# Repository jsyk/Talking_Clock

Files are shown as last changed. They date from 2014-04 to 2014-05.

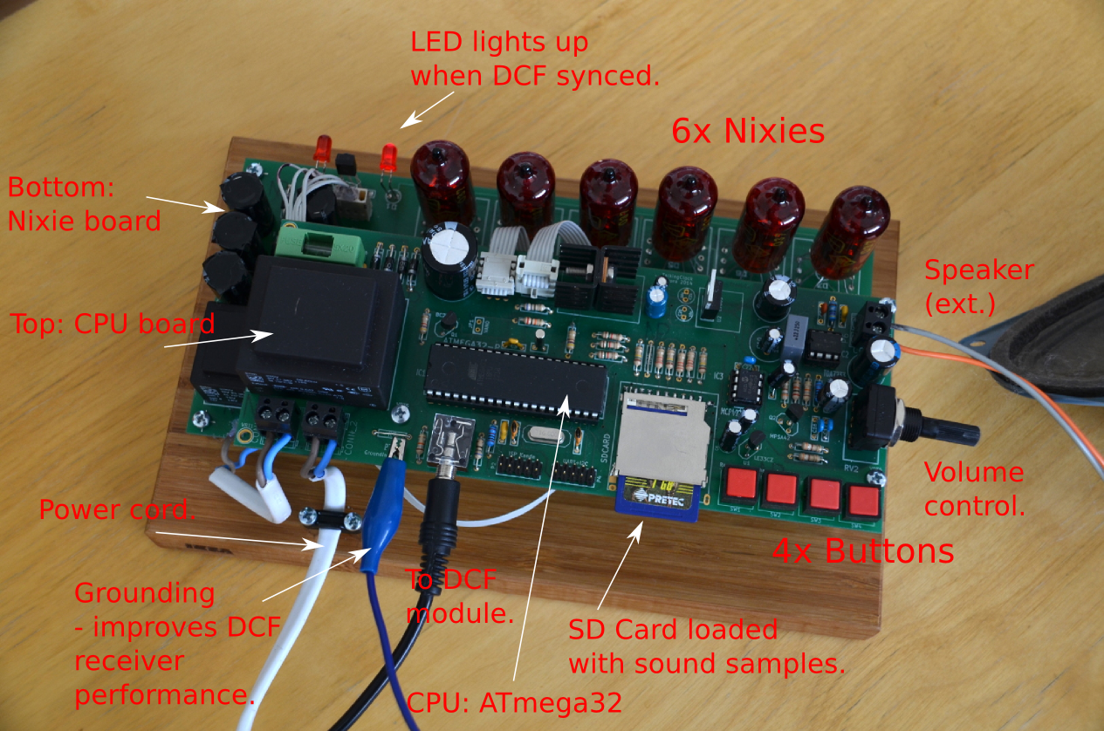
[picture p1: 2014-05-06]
doc/tc_topview_marked.png

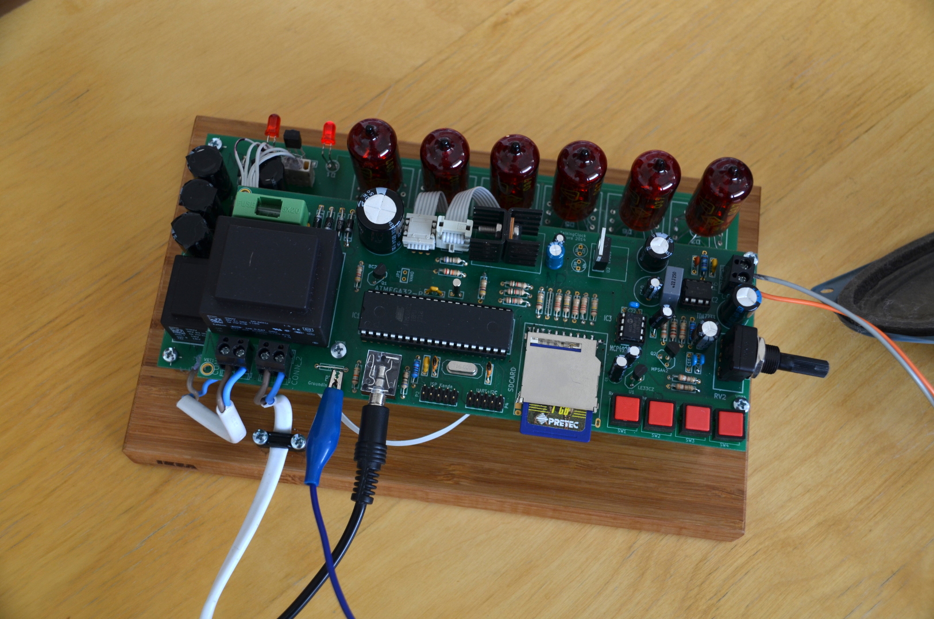
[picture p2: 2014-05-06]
doc/tc_topview.jpg

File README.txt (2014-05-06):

Talking Clock
===============

See
    http://www.jsykora.info/?page_id=240
and
    http://hackaday.io/project/1082-Talking-Nixie-Clock
for more details.

Firmware for ATMEGA32 CPU is in the sw-mega32 directory. Use AVR gcc (a package in Fedora YUM is available) to compile by Makefile, and use uisp to download compiled hex file into AVR CPU via ISP cable.
Schematic and PCB drawings in KiCAD format for the nixie board and the CPU board are in the nixieboard and rcmainboard directories, respectively.

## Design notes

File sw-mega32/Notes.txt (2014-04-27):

Use AVR gcc (a package in Fedora YUM is available) to compile via Makefile,
use uisp to download hex file into AVR CPU via ISP cable.

--------------------

uisp -dprog=stk200 --erase --upload if=dcfnix.hex --verify

uisp -dprog=stk200 --rd_fuses

picocom /dev/ttyS0 -b38400 -c

External XTAL 8MHz
    CKSEL3:1 = 111
    CKSEL0 = 1
=>
    Fuse low byte = 0xEF
uisp -dprog=stk200 --wr_fuse_l=0xef

External XTAL 16MHz
    CKSEL3:1 = 111
    CKSEL0 = 1
    CKOPT = 0
=>
    Fuse low byte = 0xEF
    Fuse high byte = 0x89
uisp -dprog=stk200 --wr_fuse_l=0xef --wr_fuse_h=0x89

Calibrated internal 8MHz RC:
    CKSEL = 0100
=>
    Fuse low byte = 0xE4
uisp -dprog=stk200 --wr_fuse_l=0xe4

Calibrated internal 1MHz RC:
    CKSEL = 0001
=>
    Fuse low byte = 0xE1
uisp -dprog=stk200 --wr_fuse_l=0xe1

mpg321 "Lordi - Dynamite Toonite.mp3" -w ~/zvuk/dynamite.wav

#sox dynamite.wav -b 8 -c 1 -r 22000 -e signed-integer dynamite.raw
sox dynamite.wav -b 8 -c 1 -r 22000 -e unsigned-integer dynamite.raw

play -r 8000 -c 1 -b 16 -L -e unsigned  dyna-u16.raw
play -r 22000 -c 1 -b 8 -L -e unsigned  dynamite.raw

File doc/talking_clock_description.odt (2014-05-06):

Talking clock can tell the current time aloud in English. The time announcement is triggered by pressing a button on a remote controller. When I awake at night I cannot recognize digits on any wall clock because I don't have my dioptrical glasses on. But I can easily find remote controller and press the trigger button just by touch, and thus learn that I don't have to get up just yet (ideally).

Besides speaking, the clock has also some other notable features. Foremost, the display is realized using six nixie tubes, which give a nice orange friendly glow. Secondly, the time is continuously kept up-to-date by receiving the German public time signal DCF77 transmitted from Frankfurt at the frequency 77.5kHz and 50kW power. The transmission covers most of the Europe up to approximately 1500km from Frankfurt. Similar transmitters exist in the UK (60kHz/50kW in Teddington, Middlesex), and in the USA (60kHz/10kW in Fort Collins).

Specification:

- Display: Six cold cathode neon readout (nixie) tubes Z573M, (or 'digitrons', as we call them here)
- Time: Radio DCF77 module receives precise German time, backed up by a 32.768kHz watch crystal.
- Remote control: infra-red (IR) sensor, software decoder for Sony remote controller I’ve got
- Processor: AVR ATmega32 (8-bit, 32kB FLASH, 2kB RAM)
- Storage of voice samples on SD card (e.g. 1GB) with FAT16/32 filesystem
- Sound converter: 12-bit DAC with SPI interface (MCP4921)
- Amplifier: 1.5W (TDA7233)
- Debug: UART/RS232, AVR ISP interface

Block Scheme

Figure 1 below shows the functional block scheme of the Talking Clock. Software components are depicted by yellow boxes and hardware parts by green boxes. The software runs on ATMEGA32 controller CPU. The IR remote controller is coloured red, because it is not a part of the design: an off-the-shelf product is used.

The lower part of the scheme in Figure 1 shows blocks dedicated to time keeping functions. There are two independent sources of the time information: a DCF radio receiver, providing a precise German date and time signal, and a local “watch” crystal oscillator. The DCF radio signal is a serial stream of bits. The bit-stream is decoded in software; more information about the decoding process is given below. The current time is updated according to the local crystal oscillator, and continuously corrected by DCF information as it is decoded. The current time expressed in hours, minutes and seconds is displayed on six nixie tubes (digitrons). Each nixie tube is capable of showing digits 0-9 and a dot.

The upper part of the functional block scheme in Figure 1 shows blocks that realize time announcements using voice. An announcement is triggered at any time by pressing a dedicated button on an infra-red (IR) remote controller. An IR signal is received by the IR sensor and output as a serial stream of bits to the CPU. If the correct button has been pressed the IR decoder triggers voice announcement. Voice messages are created by sequencing independent voice samples corresponding to individual words together. For instance, suppose the current time is 11:37. The speech sequencer first plays a voice sample that says 'it is'. Then it plays samples that say 'eleven', 'hours', 'thirty-seven', and 'minutes'. Voice samples are stored in files on SD-card (using the FAT16/32 filesystem). Analogue voice signal is synthesized using 12-bit digital-to-analogue converter (DAC), amplified, and made audible by a loudspeaker.

Nixie Display

Visual display of the clock is realized by six nixie tubes. Each Z573M tube can display digits 0-9 and a dot. Nixies produce light the same way as neon bulbs. There is a single anode at the front of the tube, made from a grid of thin wires so that you can see through it. Behind the anode there are 10 cathodes physically made of thin wires and shaped as letters '0' to '9', stacked one over another. The tube lights up when a high DC voltage (around 200V) is applied between anode and one of the ten cathodes (the dot is the eleventh cathode). A nice and friendly nuclear-age orange glow will appear around the cathode that is grounded, thus illuminating a digit.

The figure below shows the block scheme of display driver circuit. Nixies are driven in a multiplex. Cathodes of identical digits of all six nixies are connected together. Each cathode set can be switched to ground by an NPN transistor. Anodes are switched by PNP transistors. The transistors are driven from a serial shift register buffer implemented by three 74HC595's. The CPU sends a 24-bit serial stream which is shifted in the register.

Nixies require high voltage around 200V DC to light up. This power is produced in a voltage quadrupler from 36V AC.

Radio Receiver

DCF77 is a German long-wave time signal and a standard-frequency radio station located in Mainflingen near Frankfurt. The transmitter frequency is 77.5kHz, the power is 50kW.

DCF77 uses amplitude shift keying to transmit digitally coded time information. The carrier signal is 77500Hz. At the beginning of each second the amplitude of the carrier is reduced to 15% of the normal for 100ms or 200ms. A 100ms reduction denotes a binary 0; a 200ms reduction is binary 1. As a special case, the last second of every minute is marked with no carrier power reduction.

The time interval for the transfer of one bit of information is 1 second, the whole frame that encodes the current date and time takes exactly 1 minute. The figure below shows mapping of the 59-bits of a one-minute frame (the 60th second is a marker that is not modulated) to minutes, hours, and date. Numbers are encoded using BCD.

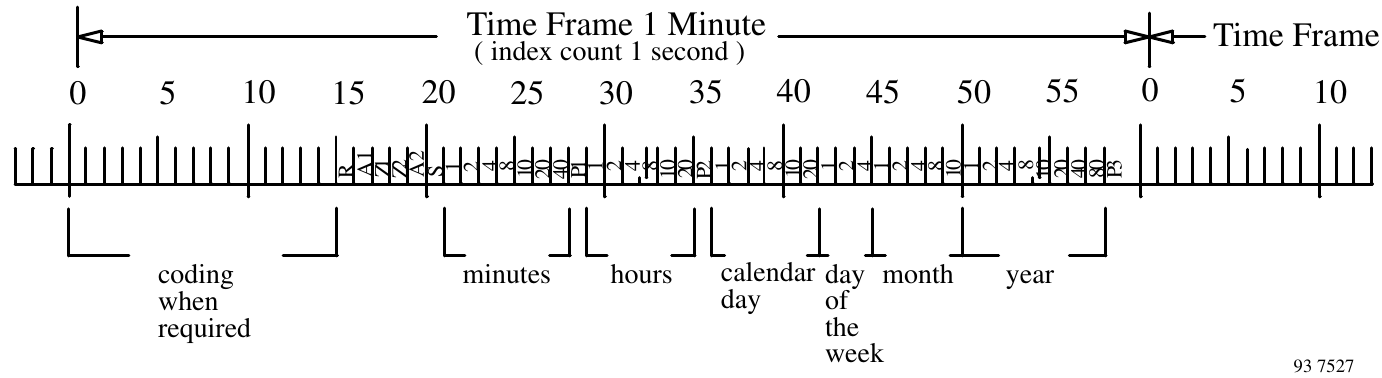
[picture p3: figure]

The talking clock uses a kit module from Flajzar that requires just power (5V), and has a single digital output corresponding to a demodulated AM signal. The module is internally realized by a ferrite antenna and U4221B integrated circuit. The output of the kit module is connected to INT1 pin at the CPU in the clock and triggers an interrupt whenever it changes level (edge detection). The interrupt routine in the CPU measures the duration of the logic levels: the duration 100ms means bit-0, and 200ms is bit-1 in the DCF bitstream. Once the whole 1-minute frame is received, it is checked for parity errors and if correct, the current time is updated to the received information.

IR Control

The clock can be controlled using an IR remote controller. The receiver module in TO92 package is mounted on the display board and connected using three wires (power and signal) the CPU board. The signal is connected to INT0 input on the CPU. Any edge triggers an interrupt. TODO Which part???

IR data is encoded by pulse width. The Sony remote that I use has three symbols that it sends: a start-bit, a zero-bit, and a one-bit. By experiment I determined that the start bit has pulse width 2.1ms to 2.75ms, one-bit is between 0.92ms and 2.1ms, zero-bit are pulses less than 0.92ms.

Each symbol (start, zero, one) is sent as a burst of on-off light pulses at the frequency roughly 38kHz. The IR module drives its output high when it detects light pulses.

http://dmohankumar.wordpress.com/2012/05/15/design-your-circuit-part-iv-ir-transmitter/

Speech

Speech synthesis is realized by playing out digital samples of individual words from SD card to DAC (digital-audio converter), and through an analogue amplifier to a loudspeaker.

Voice samples are stored in files on SD card. The SD card is formatted using standard FAT16 or FAT32 filesystem, hence the files can be normally written on any PC. The SD card hardware is connected to the ATMEGA32 CPU via SPI interface (MOSI, MISO, SCK). One minor issue is that the SD card operates on 3.3V while the rest of the design is 5V. Thankfully, all that is needed are a couple of resistors on links from CPU to the card.

The firmware has two layers of software to operate the SD-Card: SPI block-driver layer, and FAT filesystem layer. I used “Tiny FAT filesystem module” by ChaN. The SPI driver communicates with card. The card is organized into 512B-sectors. The block-layer driver can read any sector from the card and place it into internal RAM of the CPU. The FAT filesystem driver understands the FAT16/32 filesystems. It reads FAT allocation tables and directory structures. To an application it presents a simple API that allows to open a directory, list files, open a file by name, and read sequentially or randomly from the file.

Suppose the current time is 11:37. The speech sequencer first plays a voice sample that says 'it is'. Then it plays samples that say 'eleven', 'hours', 'thirty-seven', and 'minutes'. These samples are stored in files it-is.raw, n11.raw, hours.raw, n37.raw, and minutes.raw.

Sampling rate of the sound is 8kHz. Each sample is stored as 16-bit unsigned number. Samples are read from file into a working buffer (256B) and then played out at the fixed rate 8kHz through a digital-to-analog converter (DAC). The bit rate is 128kbit/s, or 16kB/s.

The DAC is connected using a separate SPI interface, which is emulated by software because ATMEGA32 has only one hardware SPI (it is used for SD-Card). The DAC is only 12-bit, hence 4 sample bits are lost. The analogue output of the DAC is filtered by a low-pass RC filter, and amplified by a single-chip 1-watt amplifier. The amplifier is powered from 12V supply.

Software

Firmware is stored in internal flash memory in the CPU. As the software must cater for several asynchronous functions concurrently, it is split in independent tasks that cooperate through shared-time multiplexing and communicate by sending messages.

Interrupt routines run in background. There are four interrupt sources: 1) precise watch-clock oscillator 32768Hz that generates periodic interrupts 128-times per second; 2) 8kHz periodic interrupt generated by CPU timer to recreate the audio sample rate; 3) burst detector in the infra-red receiver; and 4) demodulated DCF77 signal.

Low-frequency 128Hz periodic interrupt (1) is driven by external 32768Hz clock oscillator. The interrupt routine increments the current time by 1/128s.

High-frequency 8kHz periodic interrupt (2) is driven by an internal timer and the clock is derived from a CPU crystal oscillator, which is typically rather imprecise. It is used to drive the Nixie tube display multiplex (at roughly 1kHz frequency) and to output audio samples to DAC if sound is playing.

The IR burst detector (3) and DCF77 demodulator (4) each drive a separate interrupt pin at the CPU. Interrupts are generated at both the rising and falling edges of signals. The interrupt routines measure time intervals between edges, and decode signals accordingly.

Interrupt routines run in background. In foreground there are 7 `processes' which are executed in a loop. Technically, the system implements shared-time multiprocessing with message passing. Each `process' is a function with a single argument `const message_t *msg' – a pointer to the current message. The function can react to the message, it can create and send (enqueue) new messages, or it can do any other processing.

Processes:

voice_process() - Sequences current time into file names of samples that shall be played.

recv: Cmd_SayTime, Cmd_FinishedPlay; send: Cmd_PlayFileName

vfs_process()- Opens file by name and passes the handle to sound player.

recv: Cmd_PlayFileName; send: Cmd_PlayFileHandle

sound_process()- Receives file handle from VFS process, reads samples from the file and sends them at fixed rate to DAC.

recv: Cmd_PlayFileHandle; send: Cmd_FinishedPlay

ir_process()- Retrieves decoded word from IR receiver, compares to known codewords, sends Cmd_SayTime if the correct button has been pressed.

send: Cmd_SayTime

debug_process()- Communicates over UART for debug.

send: Cmd_SayTime, Cmd_PlayFileName

btn_process()- Checks hardware buttons on the CPU board.

recv: Cmd_ClockTick

clock_process()- Sends periodic clock event messages.

send: Cmd_ClockTick

Mechanical Construction

The system has two PCB boards: display board with nixies and high-voltage electronics, and CPU board with ATMEGA32, SD-Card, and sound subsystem. The CPU board is mounted over the display board and a little bit behind, so the two boards form a cascade. The board assembly is mounted on a wooden baseplate--I used a small chopping desk from Ikea. No other cover is used because I like having electronics exposed.

Errata

The PCB board has a couple of bugs, and they should be fixed by anyone wishing to replicate the design.

- Connector P1 on CPU board is package DIP-6__300ELL, but the corresponding connector P1 on nixie board is package 6DIP-CONN. While the physical footprints on PCB are the same, the logical assignment of signals to pins is different! Hence a straight flat cable between the connectors will connect incorrect signals. Suggested correction: change package and reroute a part of one of the boards.
- Drill holes for potentiometer RV2 on CPU board are small.
- Drill holes for buttons on CPU board are small.

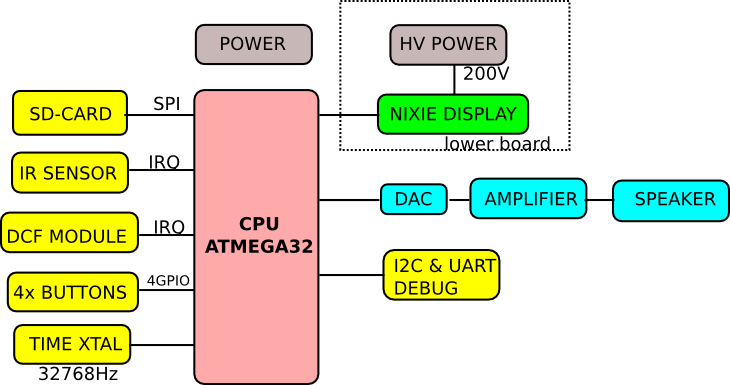
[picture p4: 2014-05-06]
doc/talkingclock_block_scheme.png

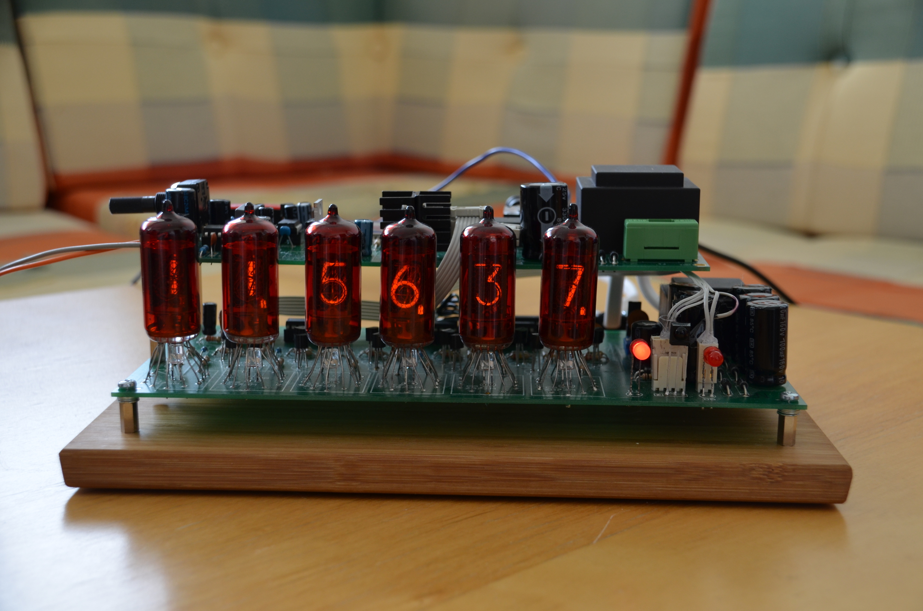
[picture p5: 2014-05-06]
doc/tc_front.JPG

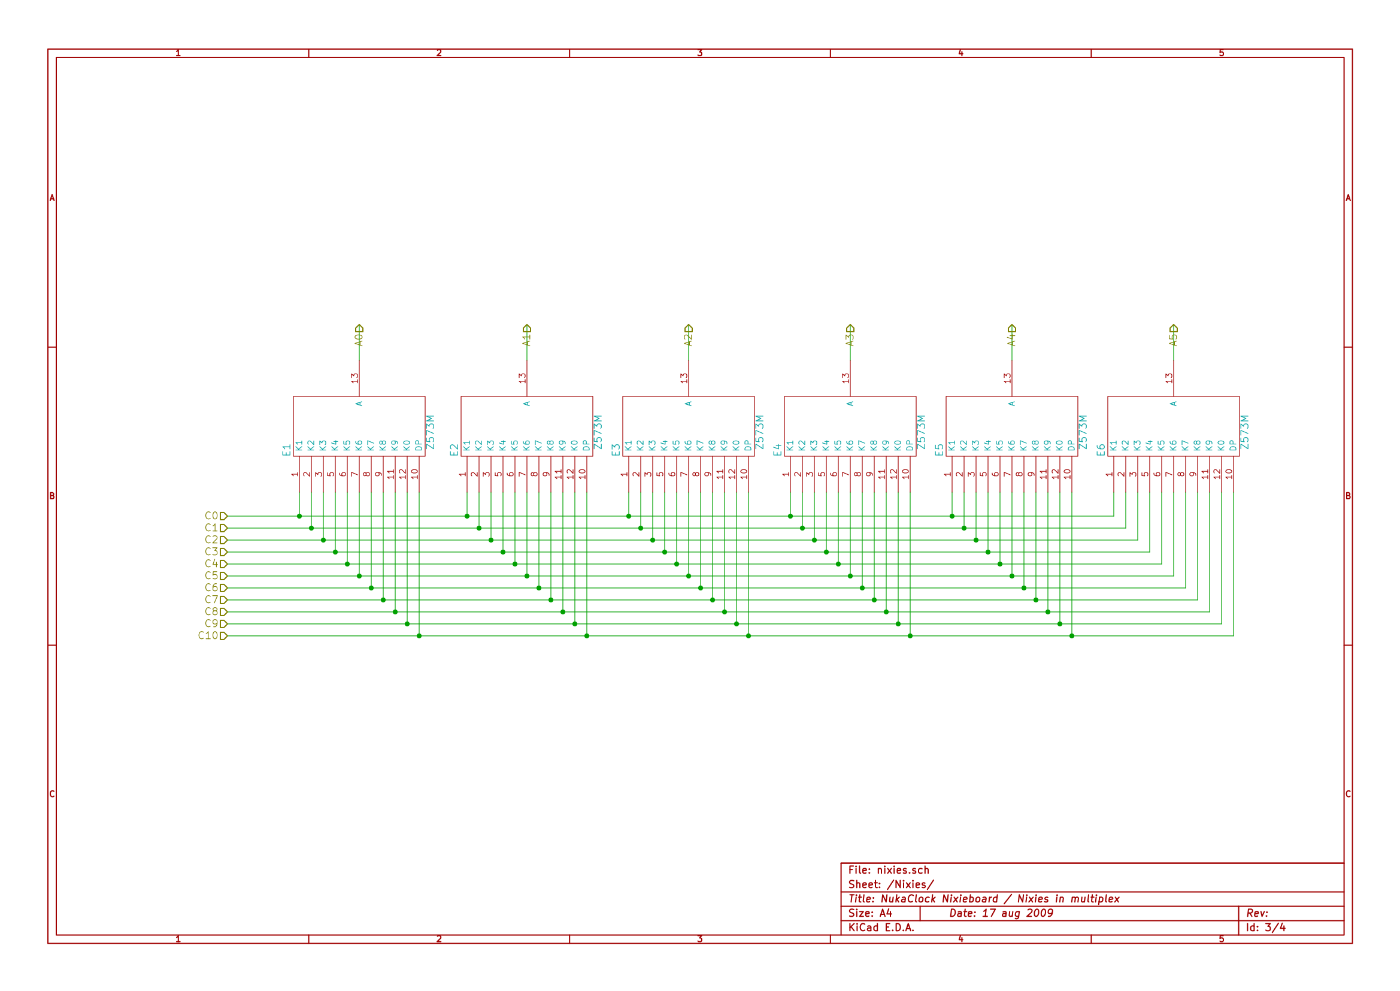
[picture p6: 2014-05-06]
doc/nixieboard_sch_nixies.png

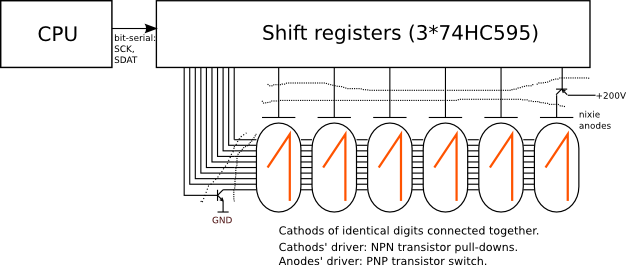
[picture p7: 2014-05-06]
doc/tc_nixie_display.png

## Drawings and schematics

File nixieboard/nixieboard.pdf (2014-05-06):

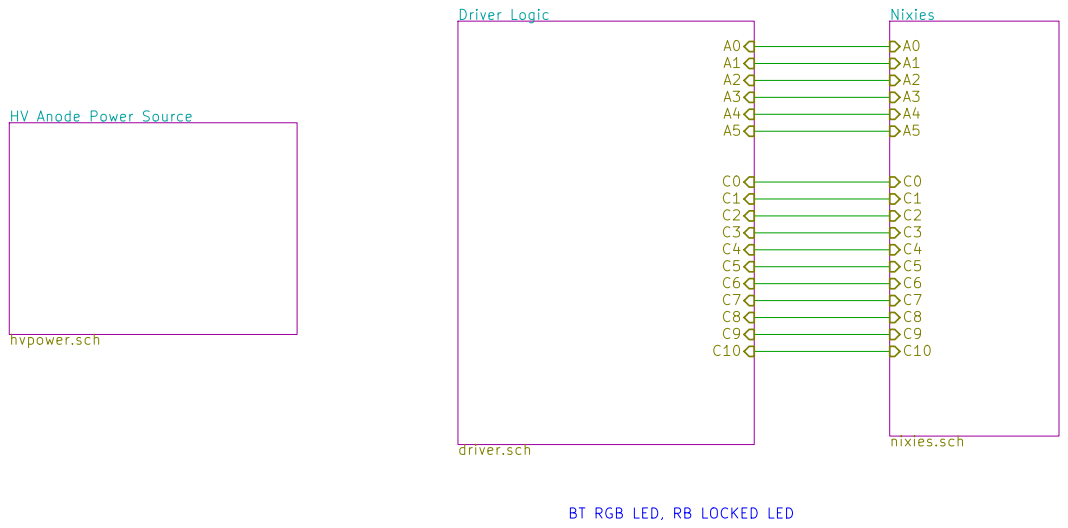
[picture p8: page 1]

HV Anode Power Source

BT RGB LED, RB LOCKED LED

Title: NukaClock Nixieboard File: nixieboard.sch Sheet: /

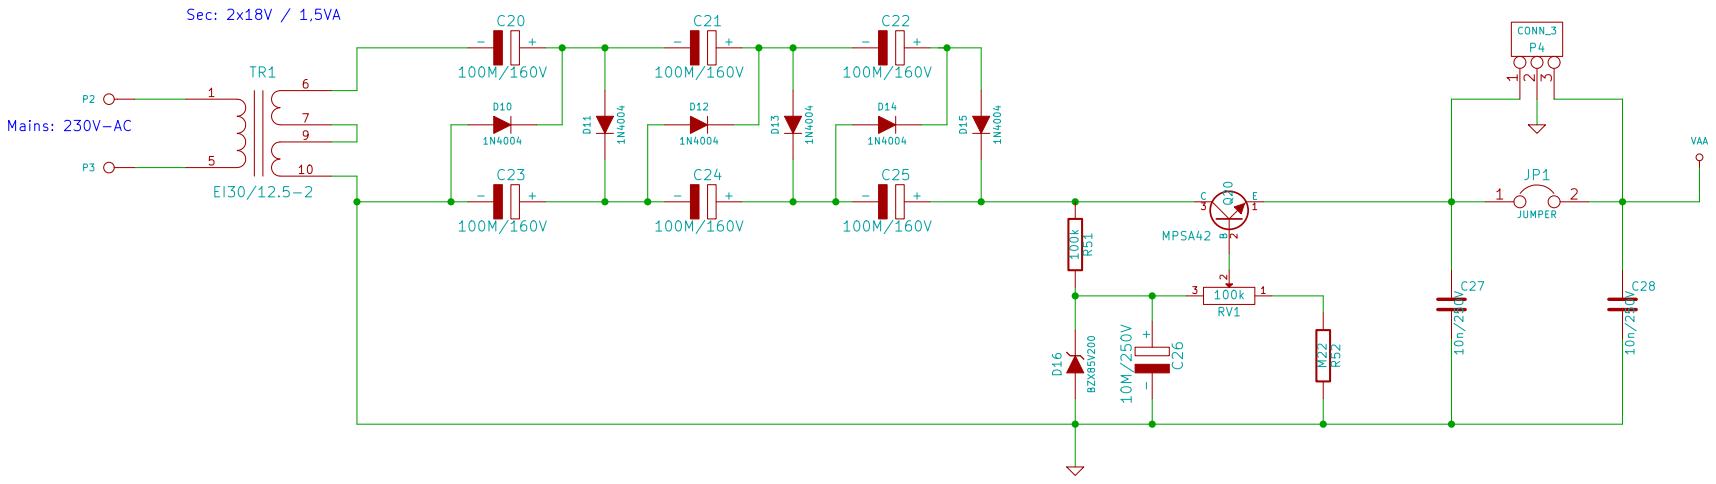
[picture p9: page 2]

File: hvpower.sch
Sheet: /HV Anode Power Source/
Title: NukaClock Nixieboard / High voltage anode power supply

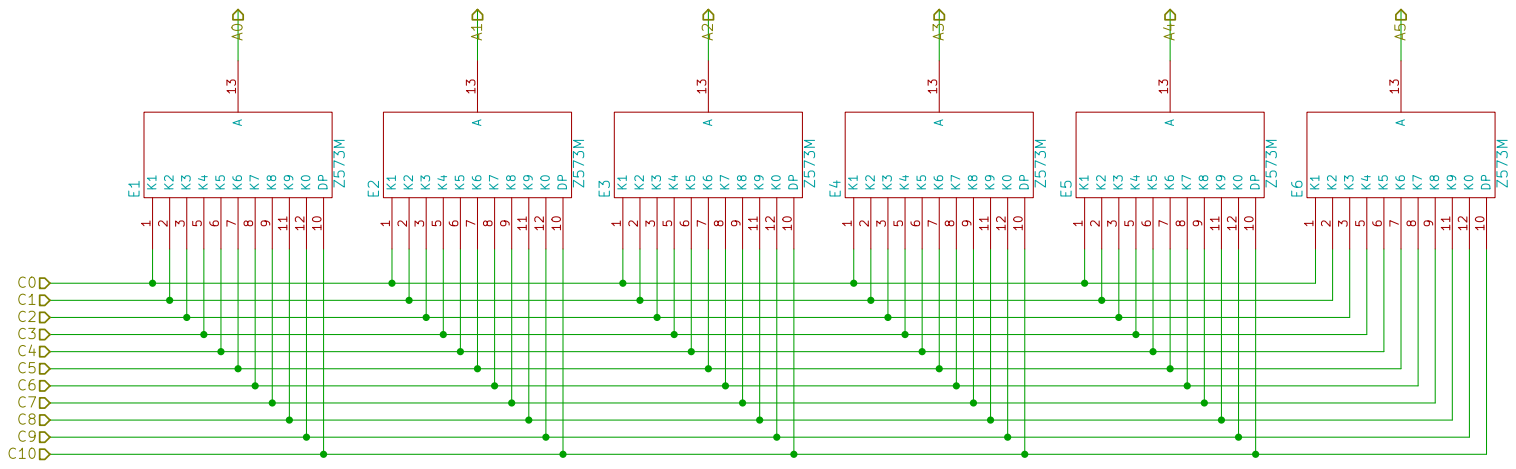
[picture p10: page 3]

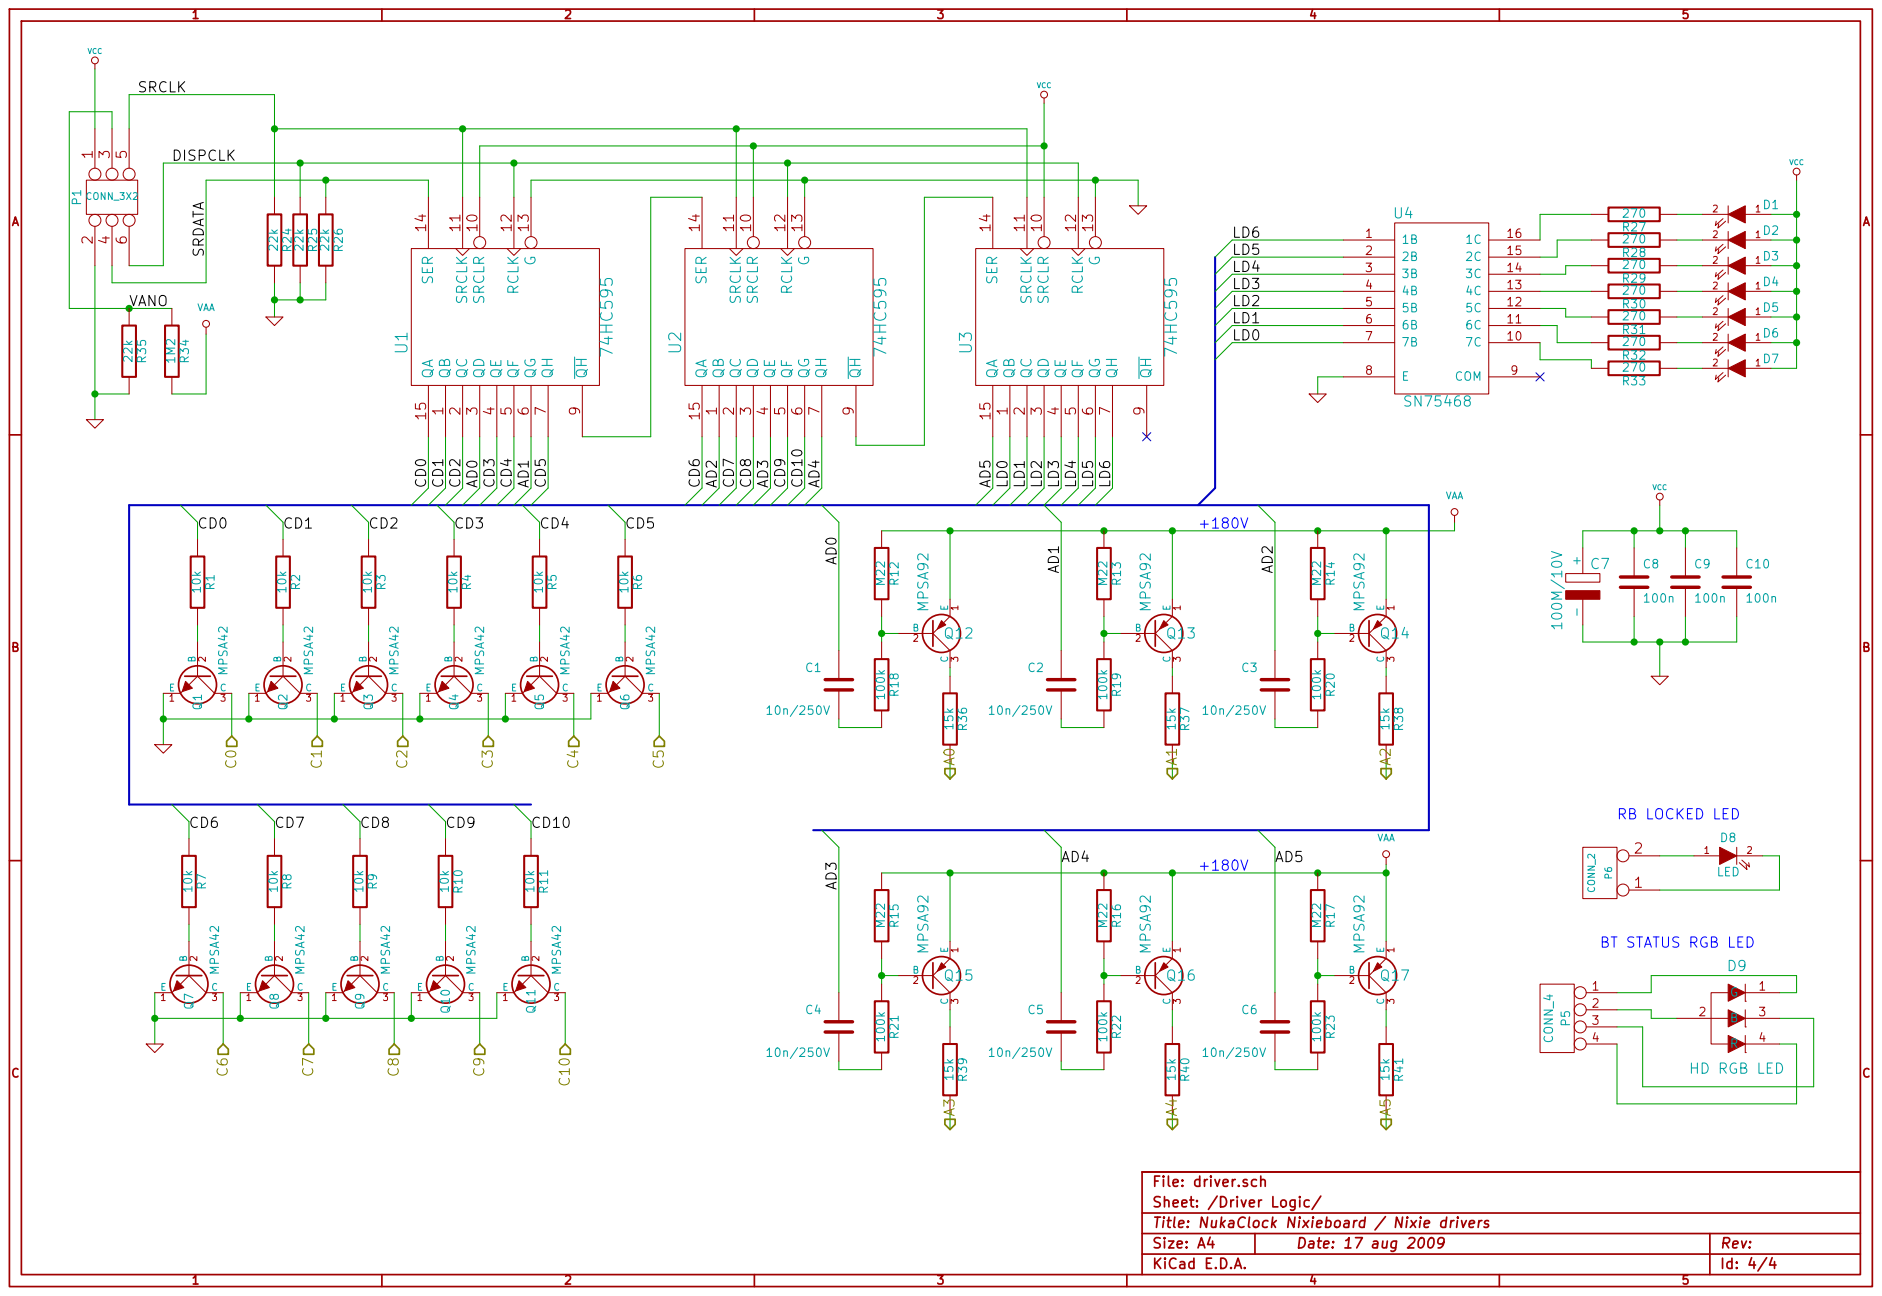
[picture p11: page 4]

VCC BT STATUS RGB LED

9 SRCLR 10 SRCLK 11 RCLK 12 G 13 SER 14 QA 15 U174HC595

9 SRCLR 10 SRCLK 11 RCLK 12 G 13 SER 14 QA 15 U274HC595 QB

9 SRCLR 10 SRCLK 11 RCLK 12 G 13 SER 14 QA 15 U374HC595 QB

Title: NukaClock Nixieboard / Nixie drivers File: driver.sch Sheet: /Driver Logic/

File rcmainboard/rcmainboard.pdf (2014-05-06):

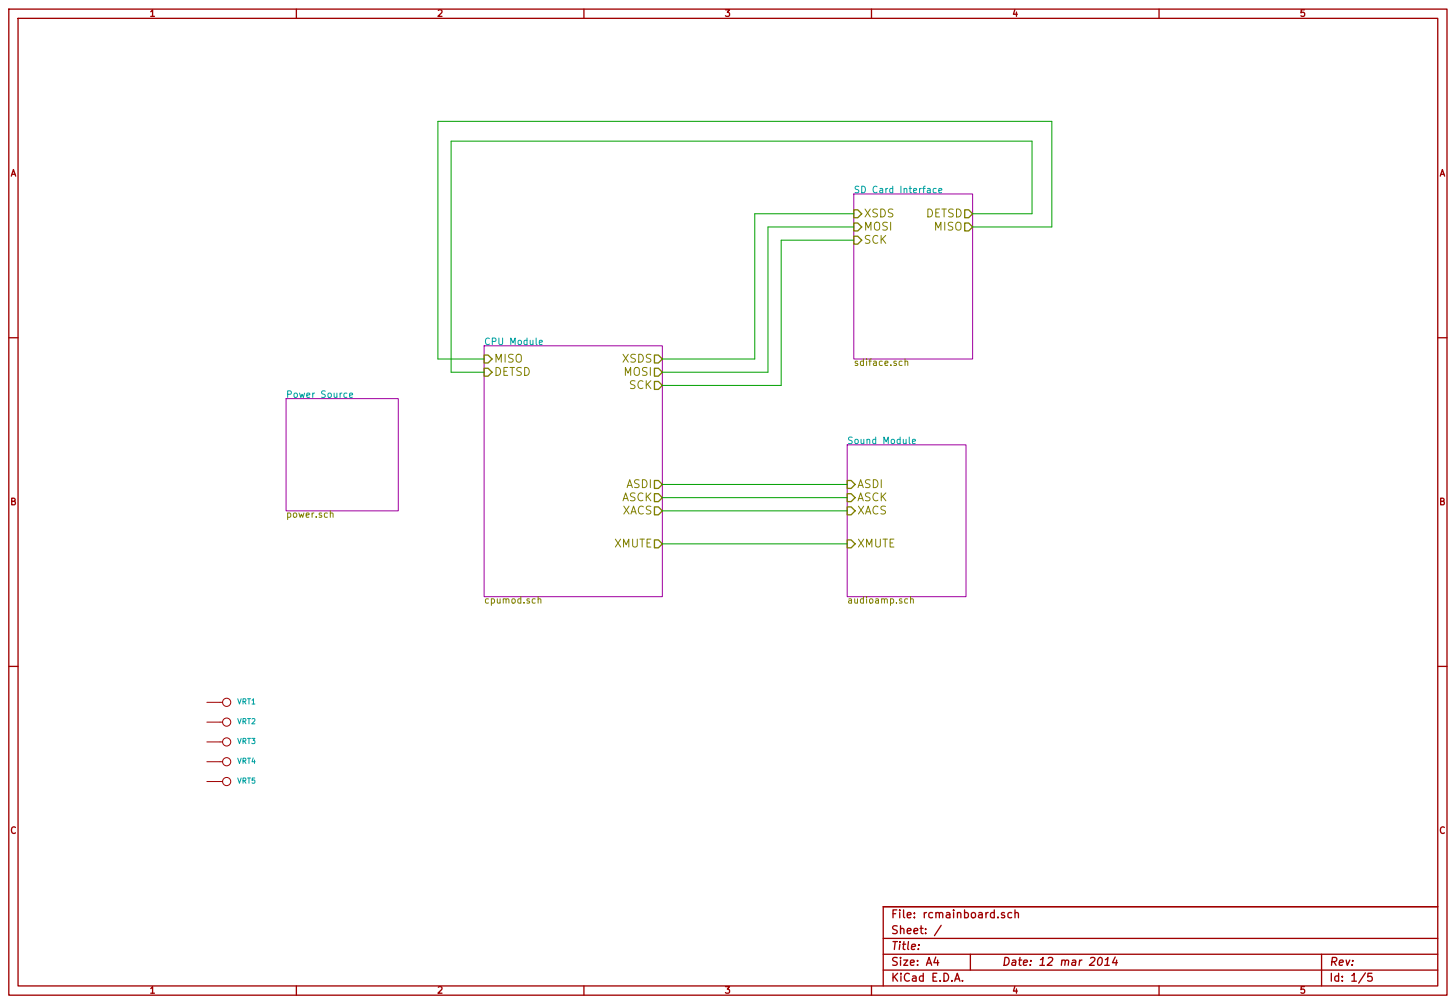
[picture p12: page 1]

Id: 1/5 Title: File: rcmainboard.sch Sheet: /

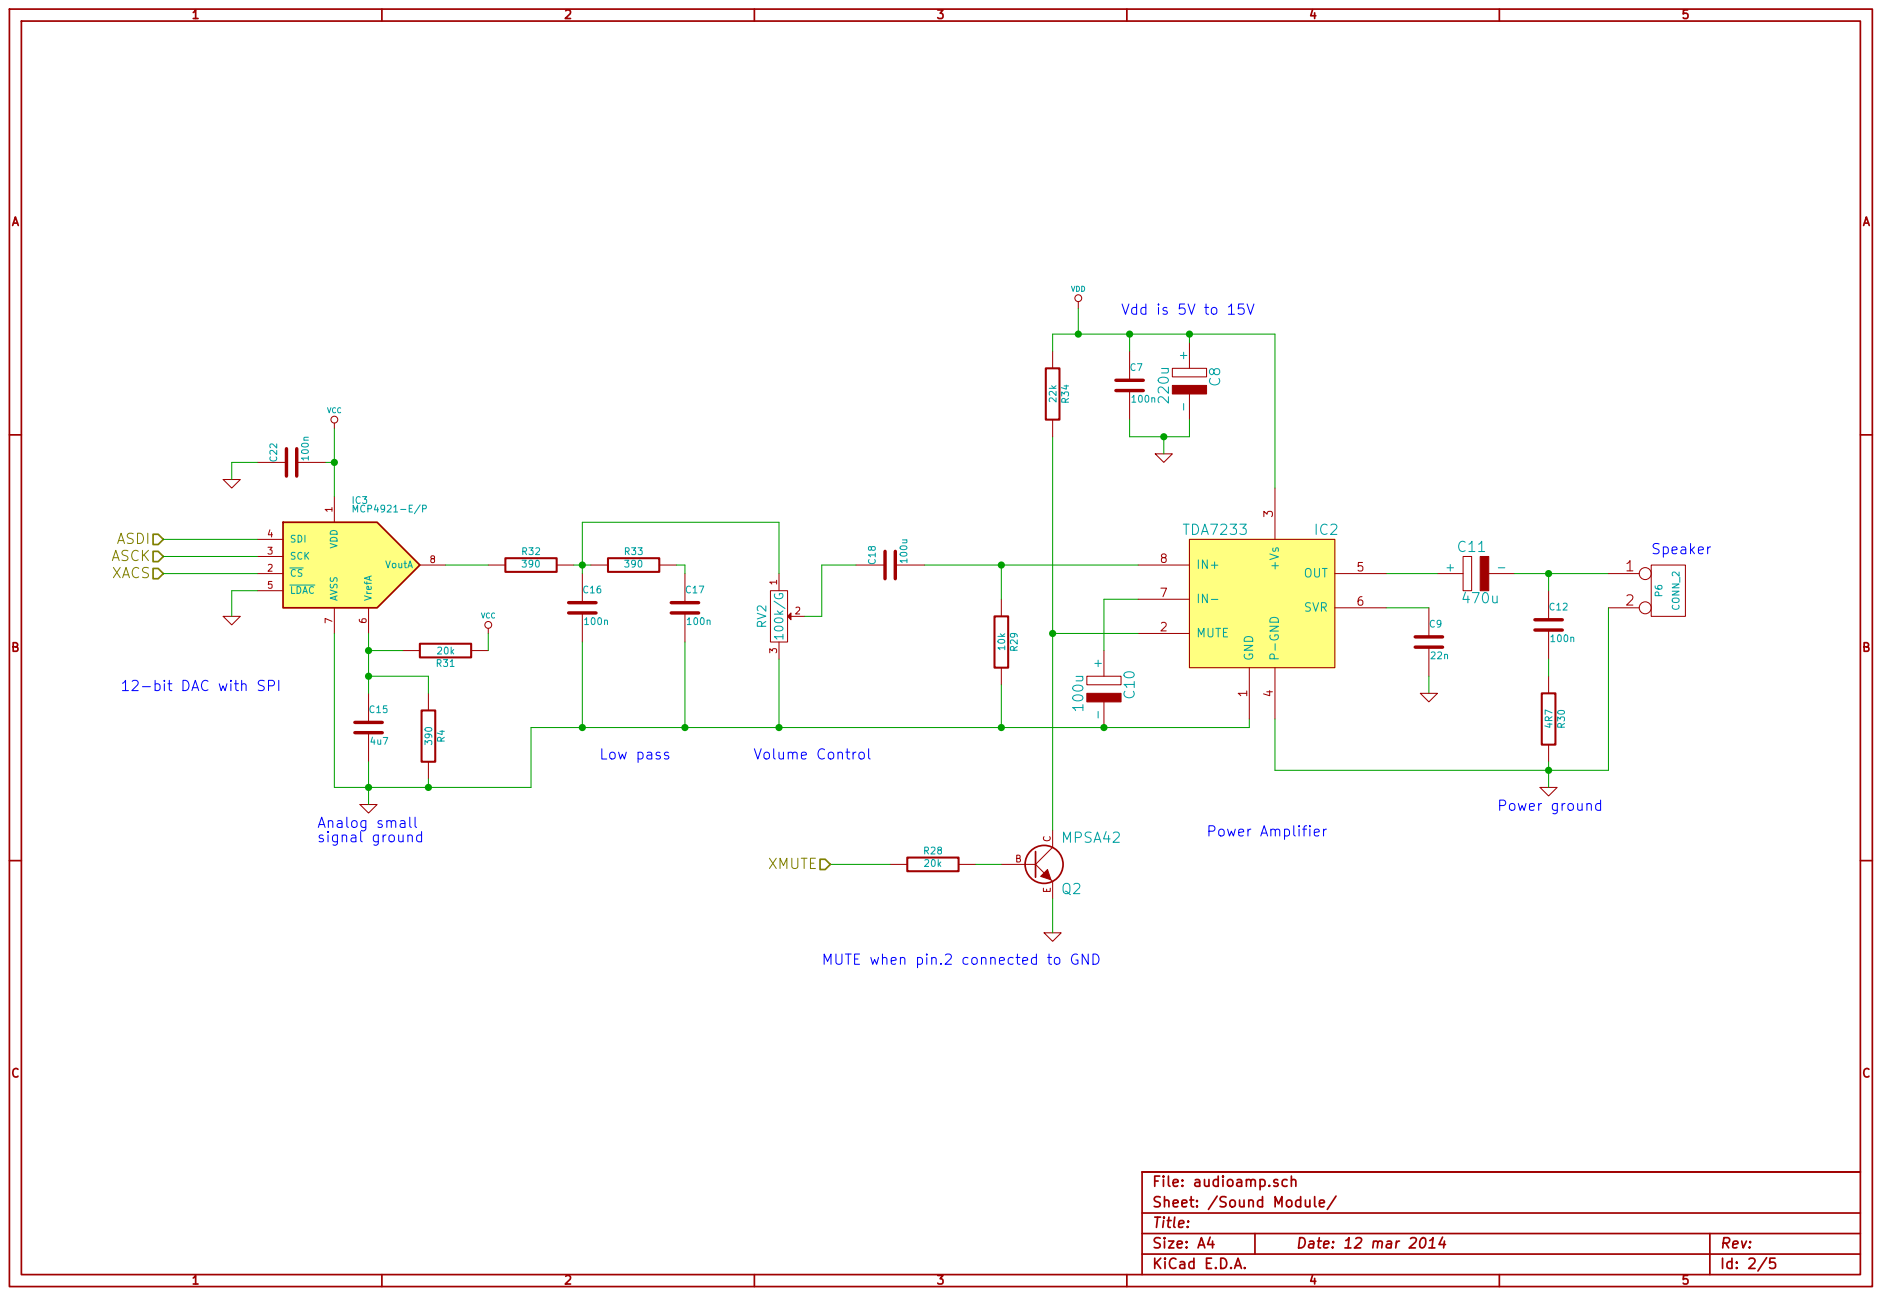
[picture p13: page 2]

MUTE when pin.2 connected to GND VDD

12-bit DAC with SPI

Id: 2/5 Title: File: audioamp.sch

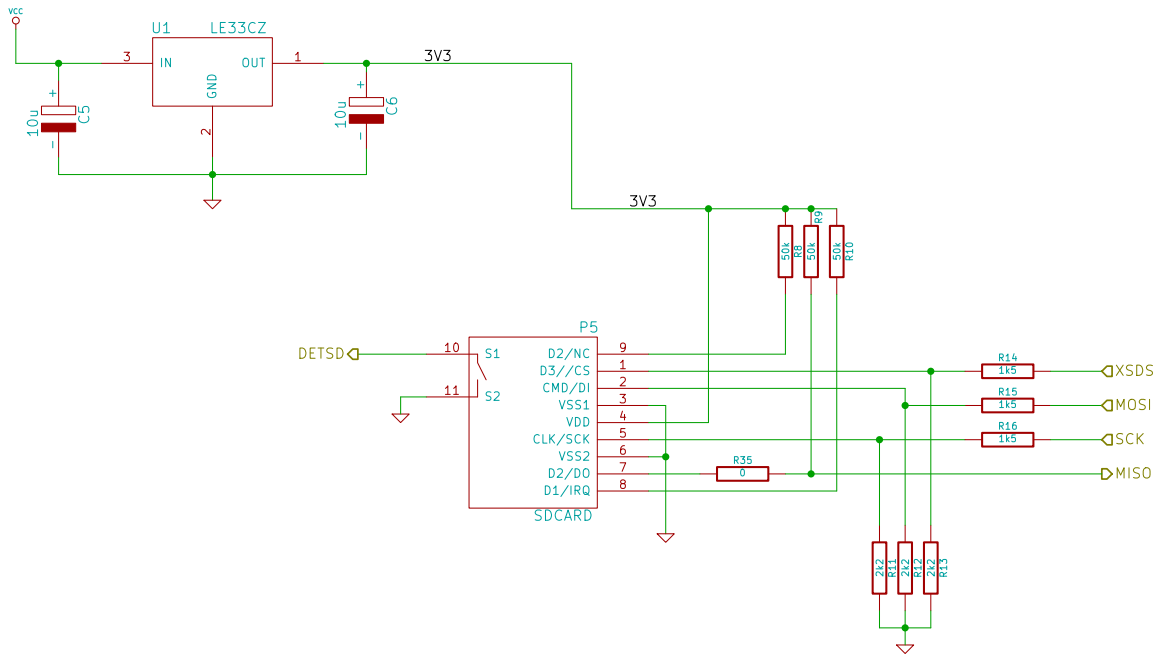
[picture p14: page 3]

Id: 3/5 Title: File: sdiface.sch Sheet: /SD Card Interface/

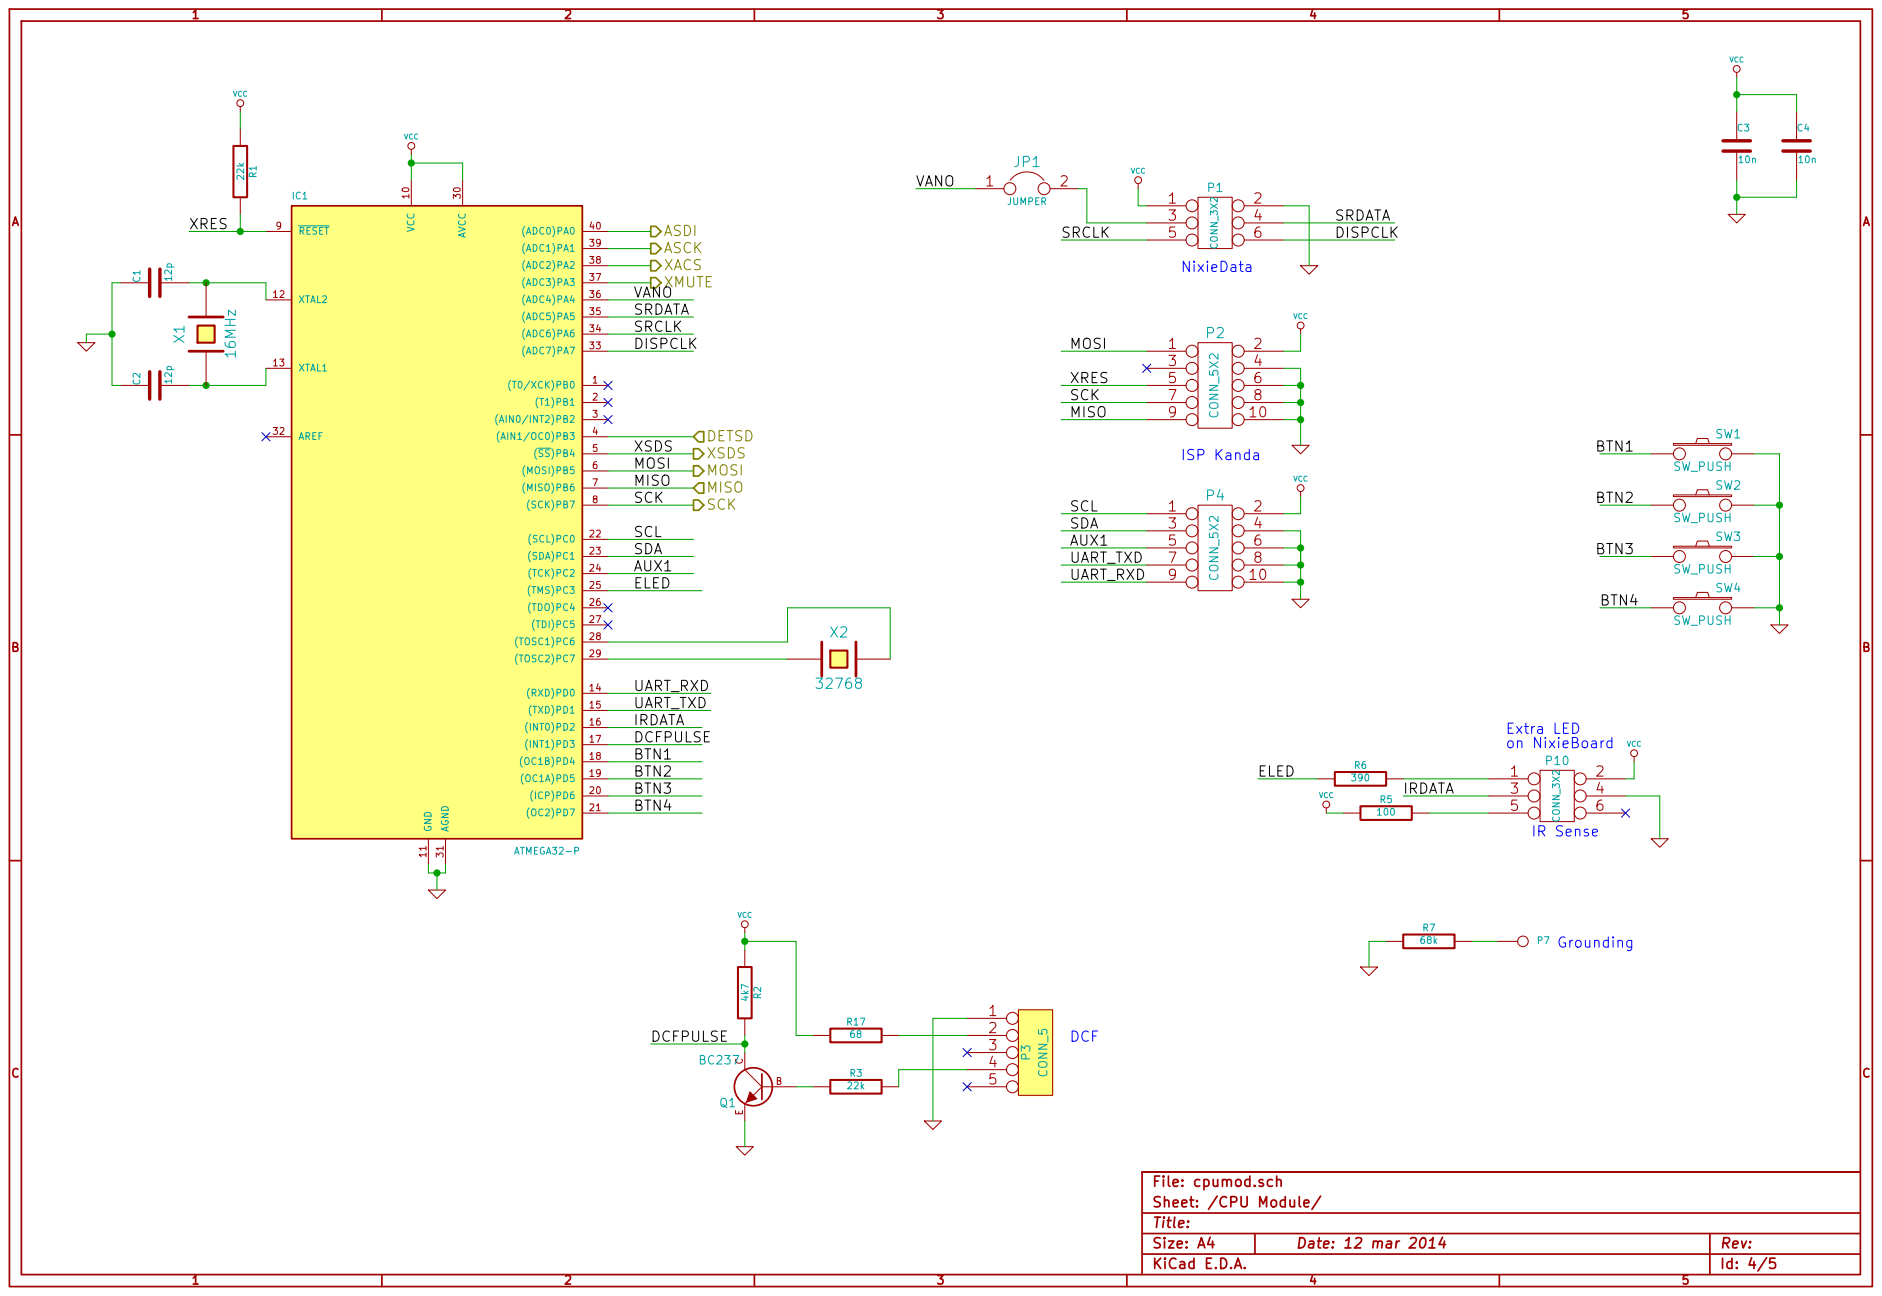
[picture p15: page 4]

Id: 4/5 Title: File: cpumod.sch
Sheet: /CPU Module/

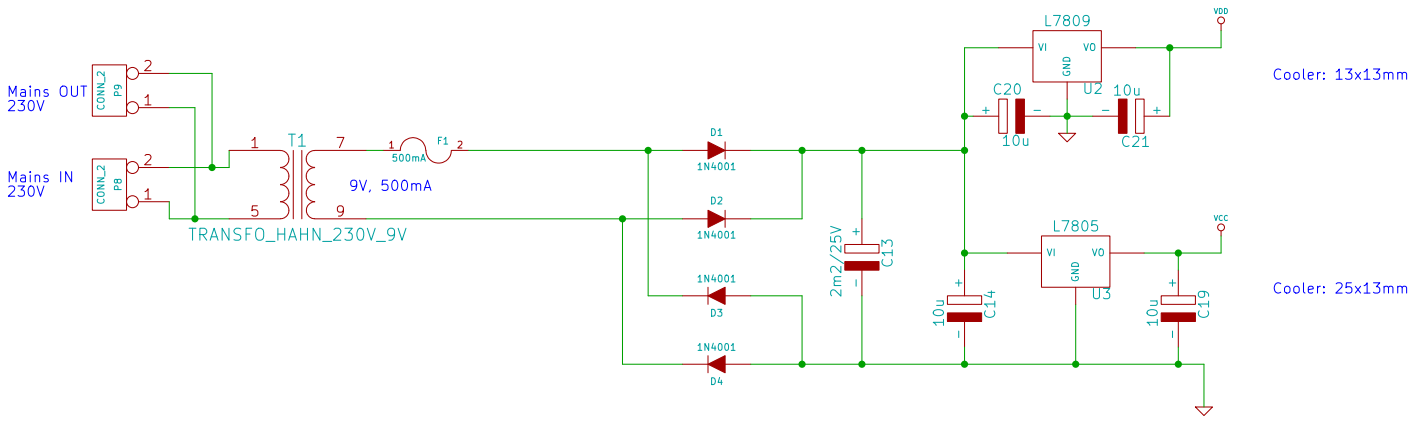
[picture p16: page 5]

Id: 5/5 Title: File: power.sch
Sheet: /Power Source/

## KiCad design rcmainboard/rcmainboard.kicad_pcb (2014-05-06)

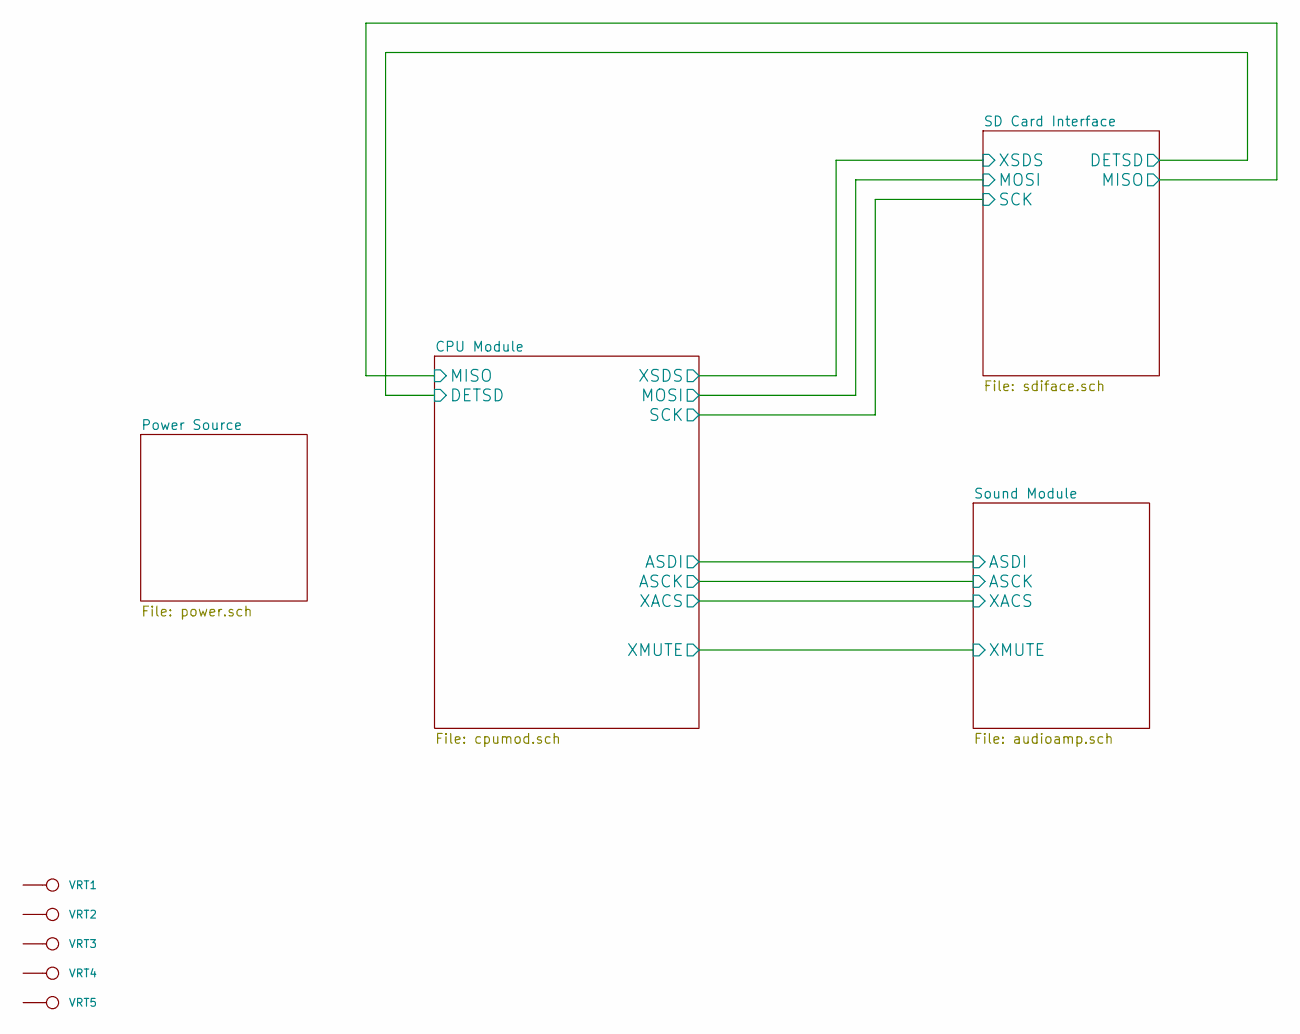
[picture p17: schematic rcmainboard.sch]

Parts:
VRT1, VRT2, VRT3, VRT4, VRT5: CONN_1

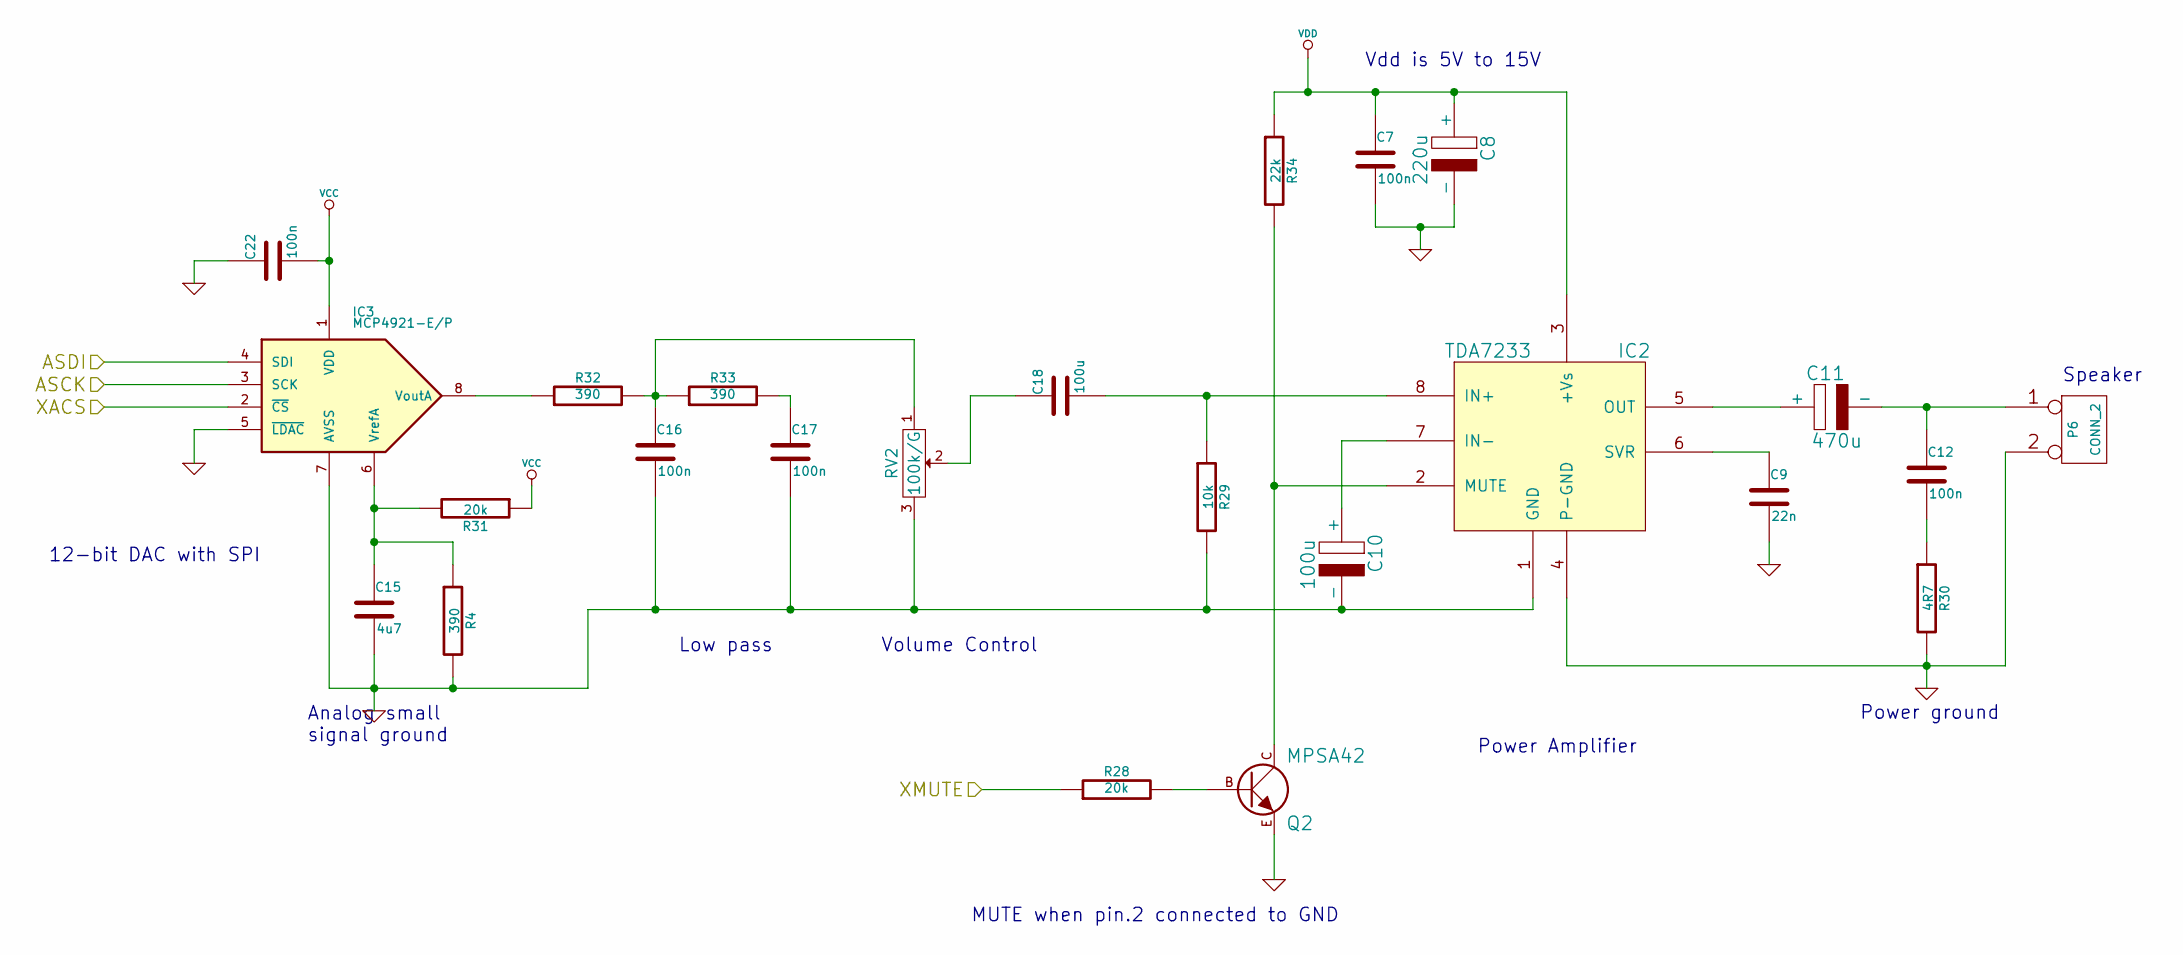
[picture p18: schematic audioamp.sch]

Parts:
C7, C12, C16, C17, C22: 100n; C2
C8: 220u; C2V10
C9: 22n; C2
C10: 100u; C2V10
C11: 470u; C2V10
C15: 4u7; C2
C18: 100u; C2
IC2: TDA7233; DIP-8__300_ELL
IC3: MCP4921-E/P; DIP-8__300_ELL
P6: CONN_2; AK300-2
Q2: MPSA42; TO92-CBE
R4, R32, R33: 390; R4
R28, R31: 20k; R4
R29: 10k; R4
R30: 4R7; R4
R34: 22k; R4
RV2: 100k/G; POTA_Fav

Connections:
/CPU Module/ASCK: IC3.3 (SCK); also elsewhere on the board
/CPU Module/ASDI: IC3.4 (SDI); also elsewhere on the board
/CPU Module/XACS: IC3.2 (~CS~); also elsewhere on the board
/CPU Module/XMUTE: R28.1; also elsewhere on the board
GND: C7.2, C8.2 (-), C9.2, C10.2 (-), C15.2, C16.2, C17.2, C22.1, IC2.1 (GND), IC2.4 (P-GND), IC3.5 (~LDAC~), IC3.7 (AVSS), P6.2 (PM), Q2.E, R4.2, R29.2, R30.2, RV2.3; also elsewhere on the board
unnamed: C12.2, R30.1
unnamed: IC2.2 (MUTE), Q2.C, R34.2
unnamed: C9.1, IC2.6 (SVR)
unnamed: C11.1 (+), IC2.5 (OUT)
unnamed: C10.1 (+), IC2.7 (IN-)
unnamed: Q2.B, R28.2
unnamed: C11.2 (-), C12.1, P6.1
unnamed: C17.1, R33.2
unnamed: C15.1, IC3.6 (VrefA), R4.1, R31.2
unnamed: C18.1, RV2.2
unnamed: C18.2, IC2.8 (IN+), R29.1
unnamed: IC3.8 (VoutA), R32.1
unnamed: C16.1, R32.2, R33.1, RV2.1
VCC: C22.2, IC3.1 (VDD), R31.1; also elsewhere on the board
VDD: C7.1, C8.1 (+), IC2.3 (+Vs), R34.1; also elsewhere on the board

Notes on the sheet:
Speaker
MUTE when pin.2 connected to GND
Vdd is 5V to 15V
Volume Control
12-bit DAC with SPI
Power Amplifier
Low pass
Analog small signal ground
Power ground

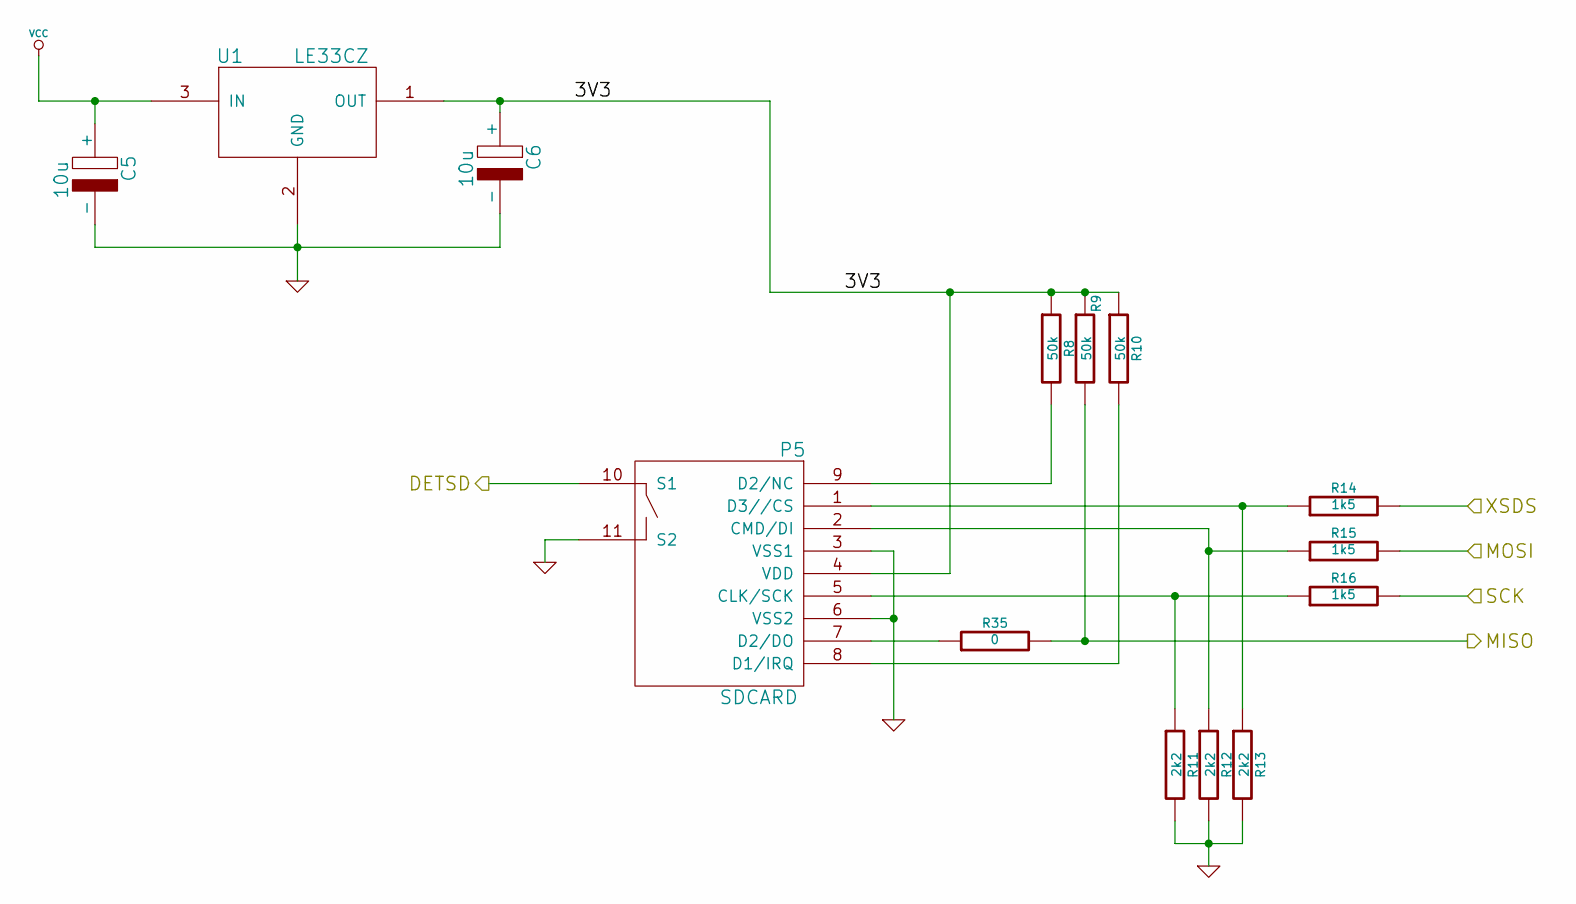
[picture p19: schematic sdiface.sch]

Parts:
C5, C6: 10u; C1V5
P5: SDCARD; SDCARD-FSIDE
R8, R9, R10: 50k; R4
R11, R12, R13: 2k2; R4
R14, R15, R16: 1k5; R4
R35: 0; R4
U1: LE33CZ; TO92-123

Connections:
/CPU Module/DETSD: P5.10 (S1); also elsewhere on the board
/CPU Module/MISO: R9.2, R35.2; also elsewhere on the board
/CPU Module/MOSI: R15.2; also elsewhere on the board
/CPU Module/SCK: R16.2; also elsewhere on the board
/CPU Module/XSDS: R14.2; also elsewhere on the board
/SD Card Interface/3V3: C6.1 (+), P5.4 (VDD), R8.1, R9.1, R10.1, U1.1 (OUT)
GND: C5.2 (-), C6.2 (-), P5.3 (VSS1), P5.6 (VSS2), P5.11 (S2), R11.2, R12.2, R13.2, U1.2 (GND); also elsewhere on the board
unnamed: P5.9 (D2/NC), R8.2
unnamed: P5.8 (D1/IRQ), R10.2
unnamed: P5.1 (D3//CS), R13.1, R14.1
unnamed: P5.7 (D2/DO), R35.1
unnamed: P5.5 (CLK/SCK), R11.1, R16.1
unnamed: P5.2 (CMD/DI), R12.1, R15.1
VCC: C5.1 (+), U1.3 (IN); also elsewhere on the board

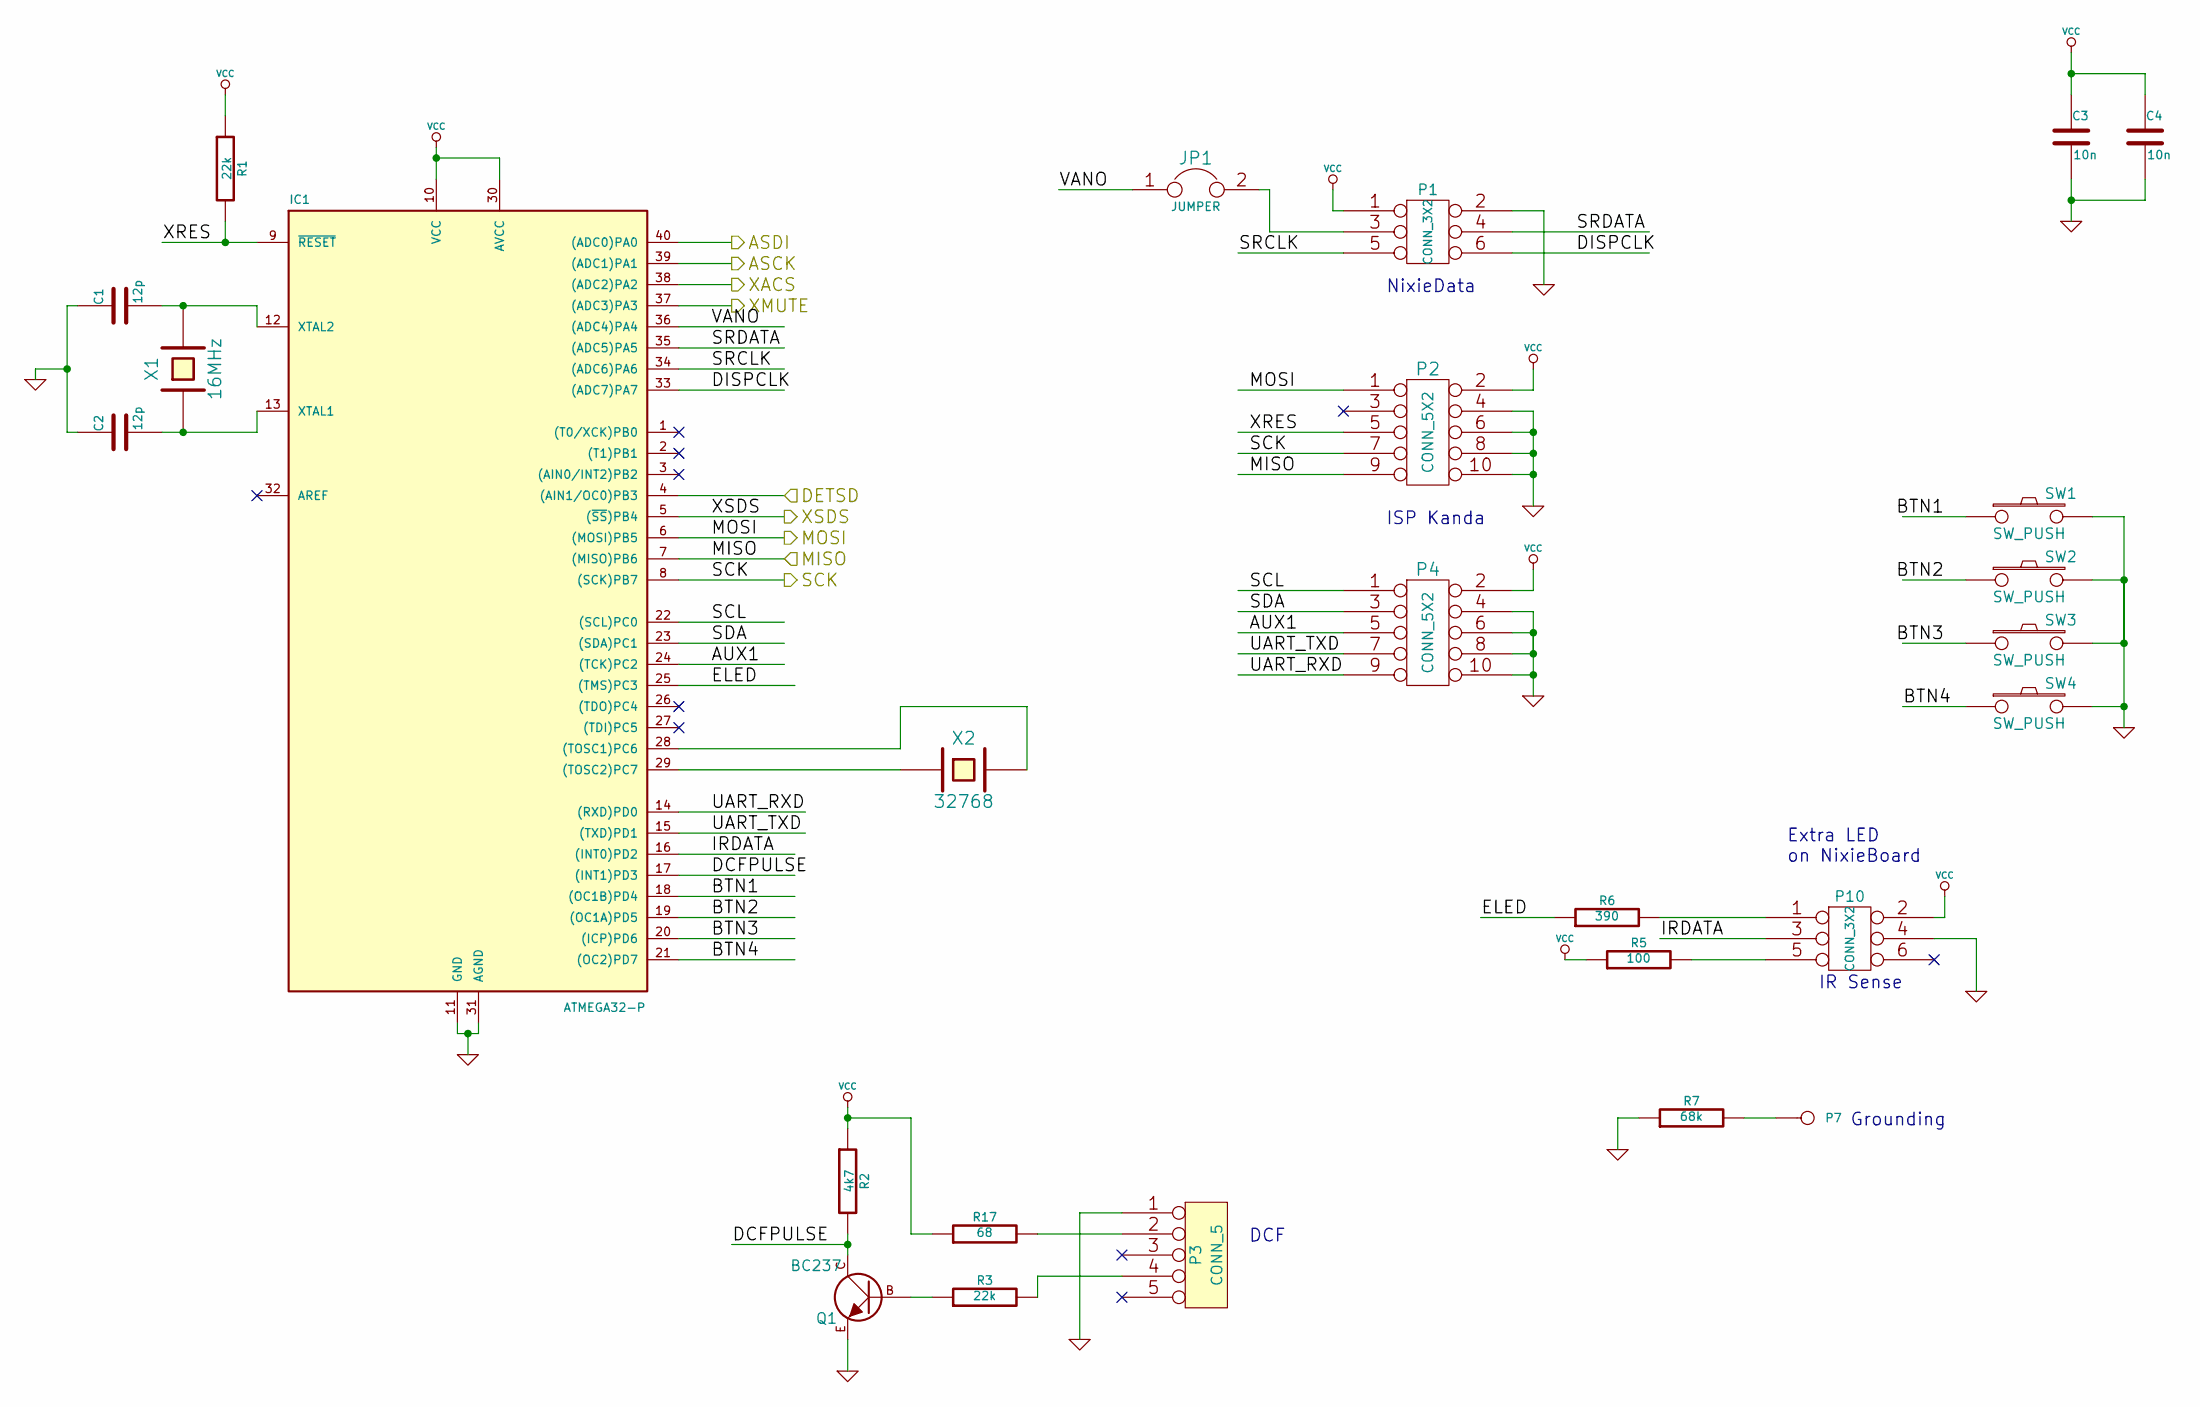
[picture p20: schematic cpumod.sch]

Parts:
C1, C2: 12p; C2
C3, C4: 10n; C2
IC1: ATMEGA32-P; DIP-40__600_ELL
JP1: JUMPER
P1: CONN_3X2; DIP-6__300_ELL
P2, P4: CONN_5X2; PIN_ARRAY_5x2
P3: CONN_5; JACK_SW_3MM
P7: CONN_1; 1pin
P10: CONN_3X2; pin_array_3x2
Q1: BC237; TO92-EBC
R1, R3: 22k; R4
R2: 4k7; R4
R5: 100; R4
R6: 390; R4
R7: 68k; R4
R17: 68; R4
SW1, SW2, SW3, SW4: SW_PUSH; SW_PUSH_10MM
X1: 16MHz; HC-18UV
X2: 32768; SIL-2

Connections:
/CPU Module/ASCK: IC1.39 ((ADC1)PA1); also elsewhere on the board
/CPU Module/ASDI: IC1.40 ((ADC0)PA0); also elsewhere on the board
/CPU Module/AUX1: IC1.24 ((TCK)PC2), P4.5
/CPU Module/BTN1: IC1.18 ((OC1B)PD4), SW1.1
/CPU Module/BTN2: IC1.19 ((OC1A)PD5), SW2.1
/CPU Module/BTN3: IC1.20 ((ICP)PD6), SW3.1
/CPU Module/BTN4: IC1.21 ((OC2)PD7), SW4.1
/CPU Module/DCFPULSE: IC1.17 ((INT1)PD3), Q1.C, R2.2
/CPU Module/DETSD: IC1.4 ((AIN1/OC0)PB3); also elsewhere on the board
/CPU Module/DISPCLK: IC1.33 ((ADC7)PA7), P1.6
/CPU Module/ELED: IC1.25 ((TMS)PC3), R6.1
/CPU Module/IRDATA: IC1.16 ((INT0)PD2), P10.3
/CPU Module/MISO: IC1.7 ((MISO)PB6), P2.9; also elsewhere on the board
/CPU Module/MOSI: IC1.6 ((MOSI)PB5), P2.1; also elsewhere on the board
/CPU Module/SCK: IC1.8 ((SCK)PB7), P2.7; also elsewhere on the board
/CPU Module/SCL: IC1.22 ((SCL)PC0), P4.1
/CPU Module/SDA: IC1.23 ((SDA)PC1), P4.3
/CPU Module/SRCLK: IC1.34 ((ADC6)PA6), P1.5
/CPU Module/SRDATA: IC1.35 ((ADC5)PA5), P1.4
/CPU Module/UART_RXD: IC1.14 ((RXD)PD0), P4.9
/CPU Module/UART_TXD: IC1.15 ((TXD)PD1), P4.7
/CPU Module/VANO: IC1.36 ((ADC4)PA4), JP1.1
/CPU Module/XACS: IC1.38 ((ADC2)PA2); also elsewhere on the board
/CPU Module/XMUTE: IC1.37 ((ADC3)PA3); also elsewhere on the board
/CPU Module/XRES: IC1.9 (~RESET), P2.5, R1.2
/CPU Module/XSDS: IC1.5 ((~SS~)PB4); also elsewhere on the board
GND: C1.1, C2.1, C3.2, C4.2, IC1.11 (GND), IC1.31 (AGND), P1.2, P2.4, P2.6, P2.8, P2.10, P3.1, P4.4, P4.6, P4.8, P4.10, P10.4, Q1.E, R7.1, SW1.2, SW2.2, SW3.2, SW4.2; also elsewhere on the board
unnamed: P7.1, R7.2
unnamed: P10.5, R5.2
unnamed: Q1.B, R3.1
unnamed: IC1.29 ((TOSC2)PC7), X2.1
unnamed: IC1.28 ((TOSC1)PC6), X2.2
unnamed: P3.4, R3.2
unnamed: P3.2, R17.2
unnamed: JP1.2, P1.3
unnamed: C2.2, IC1.13 (XTAL1), X1.1
unnamed: P10.1, R6.2
unnamed: C1.2, IC1.12 (XTAL2), X1.2
VCC: C3.1, C4.1, IC1.10 (VCC), IC1.30 (AVCC), P1.1, P2.2, P4.2, P10.2, R1.1, R2.1, R5.1, R17.1; also elsewhere on the board

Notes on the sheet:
Grounding
IR Sense
Extra LED on NixieBoard
NixieData
ISP Kanda
DCF

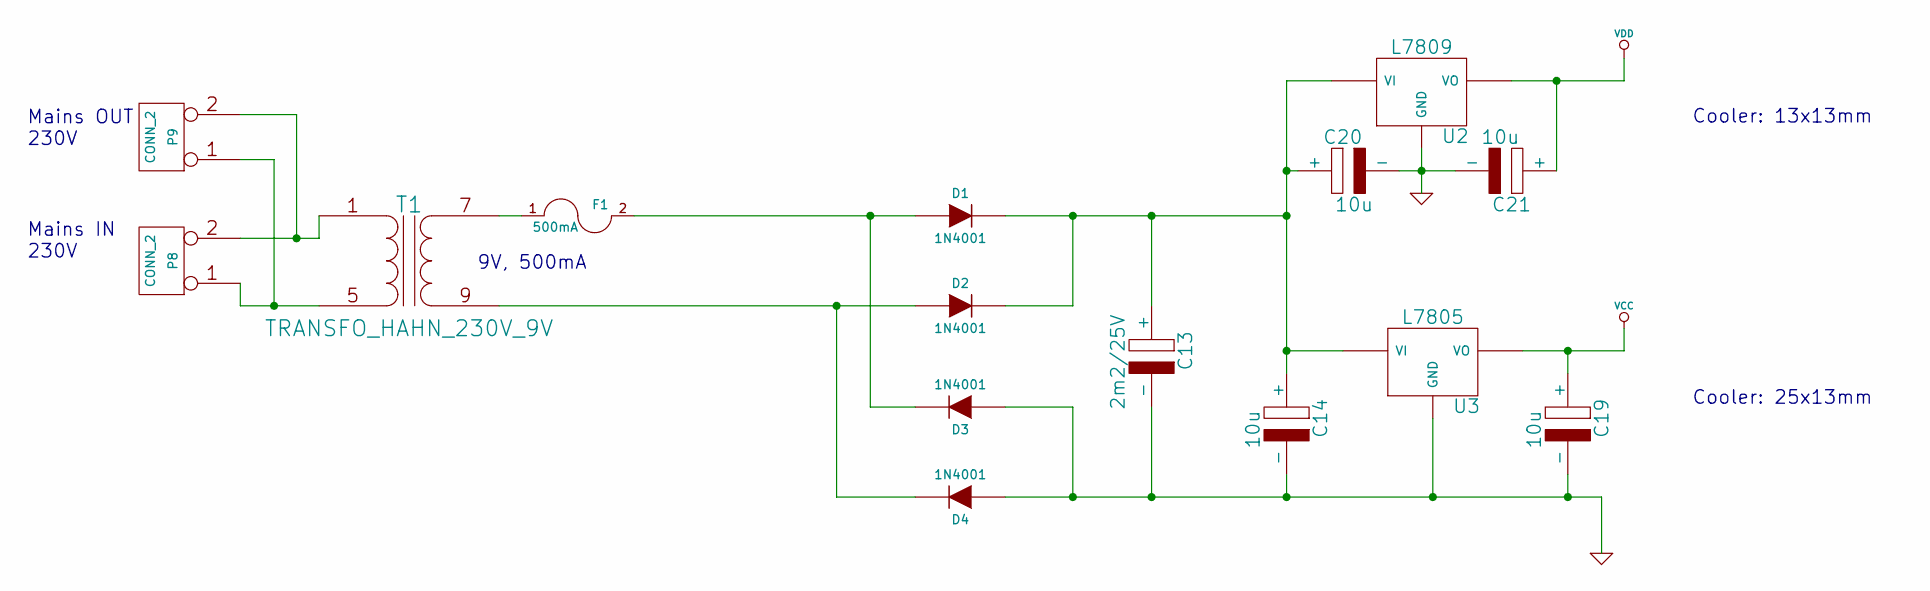
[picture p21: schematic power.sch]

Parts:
C13: 2m2/25V; CAP_8_16MM
C14, C19, C20, C21: 10u; C1V5
D1, D2, D3, D4: 1N4001; D5
F1: 500mA; Fuseholder5x20_horiz_SemiClosed_Casing10x25mm_RevA_Date25Ju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
P8, P9: CONN_2; AK300-2
T1: TRANSFO_HAHN_230V_9V; TEZ-35x42
U2: L7809; TO220vertical
U3: L7805; TO220vertical

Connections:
GND: C13.2 (-), C14.2 (-), C19.2 (-), C20.2 (-), C21.2 (-), D3.1 (A), D4.1 (A), U2.3 (GND), U3.3 (GND); also elsewhere on the board
unnamed: P8.1, P9.1, T1.5 (AB)
unnamed: F1.1, T1.7 (SB)
unnamed: P8.2 (PM), P9.2 (PM), T1.1 (AA)
unnamed: D2.1 (A), D4.2 (K), T1.9 (SA)
unnamed: D1.1 (A), D3.2 (K), F1.2
unnamed: C13.1 (+), C14.1 (+), C20.1 (+), D1.2 (K), D2.2 (K), U2.1 (VI), U3.1 (VI)
VCC: C19.1 (+), U3.2 (VO); also elsewhere on the board
VDD: C21.1 (+), U2.2 (VO); also elsewhere on the board

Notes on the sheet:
9V, 500mA
Mains IN 230V
Mains OUT 230V
Cooler: 25x13mm
Cooler: 13x13mm

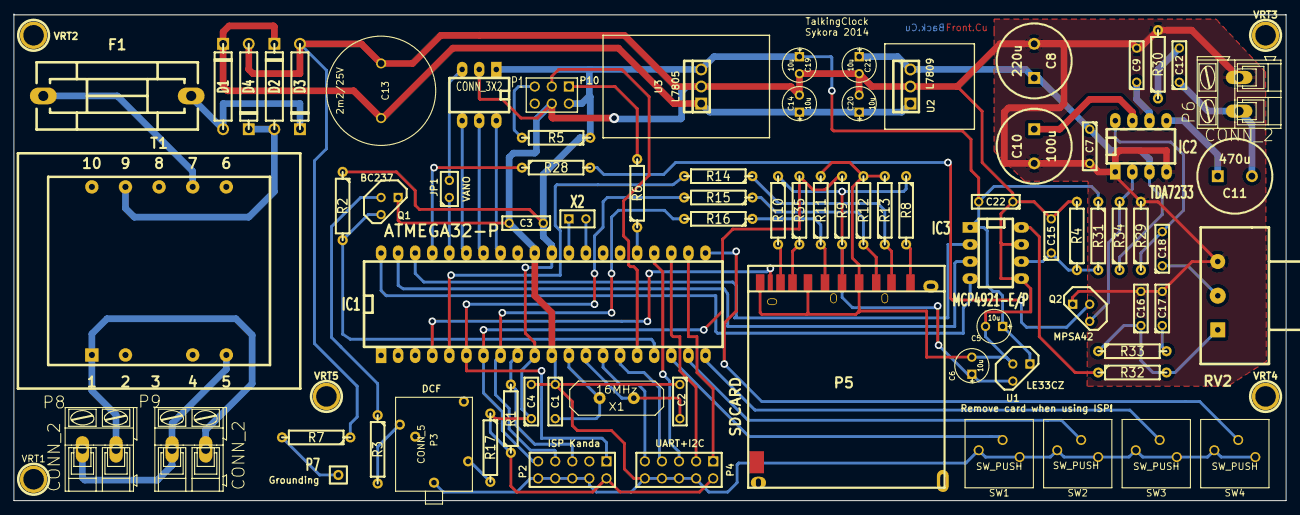
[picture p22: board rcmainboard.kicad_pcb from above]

Board: 2 copper layers, 189.2 x 72.4 mm, 84 parts (0 on the bottom side), 66 nets.

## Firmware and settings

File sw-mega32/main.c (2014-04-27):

#include "setting.h"

#include <avr/io.h>
#include <avr/pgmspace.h>
#include <avr/wdt.h>
#include <avr/interrupt.h>
#include <util/delay.h>
#include <stdlib.h>

#include "clock.h"
#include "serial.h"
#include "nixies.h"
#include "dcf.h"
#include "diskio.h"
#include "sound.h"
#include "loop.h"
#include "vfs.h"
#include "voice.h"
#include "debug.h"
#include "ir.h"
#include "btn.h"

#if 0
void cekej()
{
    int i = 1 << 15;
    while (--i)
        ;
}
#endif


#if F_CPU == 16000000L
#if SPIRATE == 250000
#define SPI_RATE_SPR    2
#define SPI_RATE_2X     0
#endif
#endif


#if F_CPU == 8000000L
#if SPIRATE == 250000
#define SPI_RATE_SPR    2
#define SPI_RATE_2X     1
#endif
#endif




/** global variables */
// extern uint8_t disp_buf[6][3];      /* FIXME: should be static in nixies.c */

volatile uint16_t current_cpu_tick = 0;


#define DS_KEEP             0
#define DS_ISR_MAIN_TIME    1

uint8_t display_state = DS_ISR_MAIN_TIME;


/* main clock, run by CPU xtal */
volatile clockinfo_t gv_clock_main = ZERO_CLOCK;       /* current running clock */
/* dcf clock */
clockinfo_t g_clock_dcf = ZERO_CLOCK;                 /* current being decoded, possibly incorrect */
clockinfo_t g_clock_dcf_last_good = ZERO_CLOCK;       /* last well-decoded dcf clock */


#if 0
uint8_t nixies_off_until_en = 0;
uint16_t nixies_off_until_tick = 0;
#endif


const uint8_t PROGMEM sin_22[22] = {
    127,   161,   193,   220,   240,   251,   254,   247,   231,   207,   178,   144,   110,    76,    
    47,    23,     7,     0,     3,    14,    34,    61 //,    93
};


/* ----------------------------------------------------- */


void show_clock_time(clockinfo_t* clk)
{
    uint8_t c_hour = clk->hour, c_min = clk->min, c_sec = clk->sec;
    uint8_t leds = 0;

    if (dcf_dec_insync) {
        if (nixies_master_mute) {
            int i;
            for (i = 0; i < dcf_dec_index / 10; ++i) {
                leds = (leds << 1) | 1;
            }
            leds <<= 1;
        }
        leds |= (dcf_dec_insync ? 1 : 0);
    }

    /* show hours */
    set_cathode_leds(0, c_hour / 10, 1, leds);
    set_cathode_leds(1, c_hour % 10, 0, leds);
    /* show minutes */
    set_cathode_leds(2, c_min / 10, 1, leds);
    set_cathode_leds(3, c_min % 10, 0, leds);
    /* show minutes */
    set_cathode_leds(4, c_sec / 10, 1, leds);
    set_cathode_leds(5, c_sec % 10, 0, leds);
}


/* ----------------------------------------------------- */
/*XXX Timer0: 1000 Hz */

#define TIM0_DIV_TO_1000        SOUND_SAMPLERATE_KHZ


/* Timer0: 22 kHz */
ISR(TIMER0_COMP_vect)
{
    static int8_t tim0_tick = TIM0_DIV_TO_1000;
#if 0
    ++current_cpu_tick;

    uint16_t d = tick_diff(current_cpu_tick, clock_last_10ms_tick);
    if (d >= 10) {
        clock_tick(&gv_clock_main, d/10);
        clock_last_10ms_tick = current_cpu_tick - (d % 10);
    }
#endif

    /* Sound */
    if (gv_sound_playing) {
        sound_isr_play();
    }

    /* Other */
    if (tim0_tick == 0) {
        /* here at 1000 Hz only */
    #if 0
        /* test Buttons */
        if (!PIN_BTN1) {
            /* Button 0 is pressed */
            nixies_off_until_en = 1;
            nixies_off_until_tick = current_cpu_tick + MS2TICK(5000*60);
            nixies_master_mute = 1;
            dcf_dec_success = 0;
        }

        if (!PIN_BTN2) {
            /* Button 1 is pressed */
            nixies_off_until_en = 0;
            nixies_master_mute = 0;
            dcf_dec_success = 0;
        }

        if (nixies_off_until_en && (nixies_off_until_tick == current_cpu_tick || dcf_dec_success)) {
            nixies_off_until_en = 0;
            nixies_master_mute = 0;
            dcf_dec_success = 0;
        }
    #endif

    #if 1
        if (display_state == DS_ISR_MAIN_TIME) {
            show_clock_time(&gv_clock_main);
        }

        if (disp_en_irq /*&& !nixies_off_until_en*/) {
            /* display write */
            isr_display_write();
        }
    #endif

        tim0_tick = TIM0_DIV_TO_1000;
    } else {
        --tim0_tick;
    }
}

/* ----------------------------------------------------- */

void print_clock_usart(clockinfo_t *clk)
{
    usart_sendhexb(clk->day);
    usart_transmit('.');
    usart_sendhexb(clk->month);
    usart_transmit('.');
    usart_sendhexb(clk->year);
    usart_transmit(' ');
    usart_sendhexb(clk->weekday);
    
    usart_transmit(' ');

    usart_sendhexb(clk->hour);
    usart_transmit(':');
    usart_sendhexb(clk->min);
    usart_transmit(':');
    usart_sendhexb(clk->sec);
    usart_transmit('.');
    usart_sendhexb(clk->msec128);
}


int main(void)
{
    // wdt_disable();              /* turn off the watchdog for this test; FIXME !! */
    wdt_enable(WDTO_500MS);

    usart_init();

    /* PORTC = Nixies */
    init_nixie_ports();

    btn_init();

    sound_init();


    /* PORTB = SD card using SPI */
    PORTB = 0b10110000;                 /* Enable drivers */
    DDRB  = 0b10110000;
    /* SPE = Enable; MSTR = Master select; SPR0 = SPI Clock rate */
    /* SPR0: 2 = f/64, 6 = f/32 */
    SPCR = (1<<SPE) | (1<<MSTR) | (SPI_RATE_SPR << SPR0);
    SPSR = (SPI_RATE_2X << SPI2X);


#if SOUND_SAMPLERATE_KHZ == 22
    /* Timer0: 22000 Hz */
#if F_CPU == 16000000L              /* 16MHz CPU clock */
    TCCR0 = (1 << WGM01) | (2 << CS00); /* CTC mode, prescaller 8 */
    OCR0 = 91;
#elif F_CPU == 8000000L             /* 8MHz CPU clock */
    TCCR0 = (1 << WGM01) | (2 << CS00); /* CTC mode, prescaller 8 */
    OCR0 = 46;
#else
    #error No constants for this F_CPU 
#endif
#endif

#if SOUND_SAMPLERATE_KHZ == 8
    /* Timer0: 8000 Hz */
#if F_CPU == 16000000L              /* 16MHz CPU clock */
    TCCR0 = (1 << WGM01) | (2 << CS00); /* CTC mode, prescaller 8 */
    OCR0 = 249;
#elif F_CPU == 8000000L             /* 8MHz CPU clock */
    TCCR0 = (1 << WGM01) | (2 << CS00); /* CTC mode, prescaller 8 */
    OCR0 = 124;
#else
    #error No constants for this F_CPU 
#endif
#endif

#if 0
    /* Timer0: 1000 Hz */
#if F_CPU == 16000000L              /* 16MHz CPU clock */
    TCCR0 = (1 << WGM01) | (3 << CS00); /* CTC mode, prescaller 64 */
    OCR0 = 250;
#elif F_CPU == 1000000L             /* 1MHz CPU clock */
    TCCR0 = (1 << WGM01) | (2 << CS00); /* CTC mode, prescaller 8 */
    OCR0 = 125;
#elif F_CPU == 8000000L             /* 8MHz CPU clock */
    TCCR0 = (1 << WGM01) | (3 << CS00); /* CTC mode, prescaller 64 */
    OCR0 = 125;
#else
    #error No constants for this F_CPU 
#endif
#endif


    /* Timer/Counter 2 in Asychronous mode, with external 32kHz Xtal */
#if 1
    ASSR = (1 << AS2);              /* enable async mode */
    // TCCR2 = (1 << WGM21) | (0b001 << CS20);        /* CTC mode, irq on COMP; clock source=clk_T2s */
    TCCR2 = (0b001 << CS20);        /* Normal mode, irq on OVF; Clock source=clk_T2s */
    TCNT2 = 0;                      /* inital counter value; not important */
    OCR2 = 255;                     /* not used on Normal mode */
    // OCR2 = 63;                     /* not used */
    /* wait until new values have been synced in hw */
    while (ASSR & 0x07)
        ;   /* wait */
#endif

    /* Timer/Counter Interrup mask register: */
    /* enable irq on OCR0 match; Enable irq in Timer2 overflow */
    // TIMSK = (1 << OCIE0) | (1 << OCIE1A);
    TIMSK = (1 << OCIE0) | (1 << TOIE2) /*| (1 << OCIE2)*/;

    /* MCUCR: MCU Control
     *  Any logical change on INT1 generates an interrupt request. [for DCF]
     *  Any logical change on INT0 generates an interrupt request. [for IR]
     */
    MCUCR = (1 << ISC10) | (1 << ISC00);

    usart_sendstr_P(PSTR("\nMCUCSR: ")); usart_sendhexb(MCUCSR);
    
    /* MCUCSR: MCU Control and status register
     * XXX ISC2=1 : External Interrupt 2 - activate on rising edge;
     * JTD=1 : Disable JTAG (! MUST WRITE TWICE !) */
    // MCUCSR = (1 << JTD) | (1 << ISC2); MCUCSR = (1 << JTD) | (1 << ISC2);
    MCUCSR = (1 << JTD); MCUCSR = (1 << JTD);
    

    /* GICR: General Interrupt Control Register
     * INT1=1 : Enable Ext.IRQ 1 (input signal DCF77) 
     * INT0=1 : Enable Ext.IRQ 1 (input signal IR receiver)
     */
    GICR = (1 << INT1) | (1 << INT0);
    
    /* rozsviti 0 na NIX0 */
    set_cathode(0, 0, 1);
    /* rozsviti 0 na NIX1 */
    set_cathode(1, 1, 1);
    /* rozsviti 0 na NIX2 */
    set_cathode(2, 2, 1);
    /* rozsviti 0 na NIX3 */
    set_cathode(3, 3, 1);
    /* rozsviti 0 na NIX4 */
    set_cathode(4, 4, 1);
    /* rozsviti 0 na NIX5 */
    set_cathode(5, 5, 1);
    
    disp_en_irq = 0xFF;

    gv_clock_main.msec128 = 0;
    gv_clock_main.sec = 0;
    gv_clock_main.min = 0;
    gv_clock_main.hour = 12;
    
    sei();
    
    loop_init();
    ir_init();
    voice_init();
    vfs_init();
    debug_init();

    loop_loop(0);
    
#if 0
    while (1) {
        usart_sendstr_P(PSTR("\nCmd? "));
        value = usart_receive();
        switch (value) {
            case 'n': {
                char val_str[10];
                usart_sendstr_P(PSTR(" / nixie num="));
                usart_getline(val_str, 10);
                uint8_t nix = hstr_to_ulong(val_str);
                usart_sendstr_P(PSTR("Symbol num [hex]="));
                usart_getline(val_str, 10);
                uint8_t symb = hstr_to_ulong(val_str);
                
                if (!(nix >= 0 && (nix <= 5 || nix == 0xA))) {
                    usart_sendstr_P(PSTR("Nixie out of range (0-5, A)\n"));
                    break;
                }
                if (symb < 0 || symb > 0x0B) {
                    usart_sendstr_P(PSTR("Symbol out of range (0-9, A, B)\n"));
                    break;
                }
                
                uint16_t cath = 0;
                if (symb < 0x0B) {
                    cath = (1 << symb);
                }
                
                disp_en_irq = 0;
                if (nix == 0xA) {
                    for (nix = 0; nix < 6; nix++) {
                        disp_buf[nix][1] = ((cath << 3) & 0xFF);
                        disp_buf[nix][2] = ((cath >> 4) & 0xFF);
                    }
                } else {
                    disp_buf[nix][1] = ((cath << 3) & 0xFF);
                    disp_buf[nix][2] = ((cath >> 4) & 0xFF);
                }
                disp_en_irq = 0xFF;
                
                usart_sendstr_P(PSTR("Cathode pattern "));
                usart_sendhexl(cath);
                usart_sendstr_P(PSTR("\n"));
                
                break;
            }
        #if 0
            case 'b': {
                nixie_counting();
                break;
            }
        #endif
            case 'h': {         //set clock
                char val_str[10];
                usart_sendstr_P(str_SetClock_EnterHour);
                usart_getline(val_str, 10);
                gv_clock_main.msec128 = 0;
                gv_clock_main.sec = 0;
                gv_clock_main.hour = hstr_to_ulong(val_str);
                usart_sendstr_P(str_EnterMinute);
                usart_getline(val_str, 10);
                gv_clock_main.min = hstr_to_ulong(val_str);
                usart_sendstr_P(str_ClockSet);
                //clock_atom = gv_clock_main;
                break;
            }
#if 0
            case 'k': {
                usart_sendstr_P(str_DisplayingClock);
                nixie_clock(&gv_clock_main);
                break;
            }
            case 'K': {
                usart_sendstr_P(str_DisplayingClock);
                nixie_clock(&clock_atom);
                break;
            }
#endif
            case 'd': {     /* DCF measure */
                uint16_t prev_done = dcf_measure_done;
                while (!usart_rx_ischar()) {
                    if (prev_done != dcf_measure_done) {
                        cli();
                        prev_done = dcf_measure_done;
                        uint16_t width = dcf_measure_width;
                        uint8_t polarity = dcf_measure_polarity;
                        sei();

#if 0
                        if (polarity) {
                            usart_sendstr_P(PSTR("H "));
                        } else {
                            usart_sendstr_P(PSTR("L "));
                        }
                        usart_sendhexl(width);
#endif
                        char decoded = decode_dcf_measurement(polarity, width);

                        if (decoded != ' ') {
                            if (decoded == '?') {
                                /* ERROR */
                                usart_transmit('(');
                                if (polarity) {
                                    usart_sendstr_P(PSTR("H "));
                                } else {
                                    usart_sendstr_P(PSTR("L "));
                                }
                                usart_sendhexl(width);
                                usart_transmit(')');
                            }

                            usart_transmit(decoded);
                            usart_transmit(',');
                            usart_sendhexb(dcf_dec_insync);
                            usart_transmit(',');
                            usart_sendhexb(dcf_dec_index);
                            usart_transmit('|');

                            if (decoded == 'M' || decoded == '?')
                                usart_send_nl();
                        }
                        
                    }

                    _delay_ms(20.0);
                }
                /* quit */
                usart_sendstr_P(PSTR("Quit!\n"));
                break;
            }
            case 'c': {
                /* print clocks */
                usart_sendstr_P(PSTR("\nMain clock:  "));      print_clock_usart(&gv_clock_main);
                usart_sendstr_P(PSTR("\nDCF good:    "));      print_clock_usart(&clock_dcf_last_good);
                usart_sendstr_P(PSTR("\nDCF current: "));      print_clock_usart(&clock_dcf);
                usart_sendstr_P(PSTR("\nMCUCSR: "));           usart_sendhexb(MCUCSR);
                // usart_sendstr_P(PSTR("\nCanaries: "));
                // usart_sendhexl(canary_1); usart_transmit(','); usart_sendhexl(canary_2); usart_transmit(','); usart_sendhexl(canary_3); usart_transmit(',');
                // usart_sendhexl(canary_4); usart_transmit(','); usart_sendhexl(canary_5); usart_transmit(','); usart_sendhexl(canary_6);
                usart_send_nl();
                break;
            }
            case 'i': {
                /* measure IR */
                uint16_t prev_done = ir_measure_done;
                uint64_t cmdcode = 0;
                uint8_t cmdlen = 0;
                while (!usart_rx_ischar()) {
                    if (prev_done != ir_measure_done) {
                        cli();
                        prev_done = ir_measure_done;
                        uint16_t width = ir_measure_width;
                        uint8_t polarity = ir_measure_polarity;
                        sei();

                        char decoded = '?';
                        if (width < 29) {
                            decoded = '0';
                        } else if (width > 29 && width < 69) {
                            decoded = '1';
                        } else if (width > 70 && width < 90) {
                            decoded = 'S';
                        } else if (width > 300) {
                            decoded = ' ';
                        }

                        usart_transmit(decoded);

                    #if 1
                        switch (decoded) {
                            case 'S': {
                                cmdcode = 0;
                                cmdlen = 1;
                                break;
                            }
                            case '0': {
                                if (cmdlen) {
                                    cmdcode <<= 1;
                                    ++cmdlen;
                                }
                                break;
                            }
                            case '1': {
                                if (cmdlen) {
                                    cmdcode = (cmdcode << 1) | (uint64_t)1;
                                    ++cmdlen;
                                }
                                break;
                            }
                            case ' ': {     /* stop */
                                /* code complete */
                                usart_transmit('=');
                                usart_sendhexl(cmdcode >> 32); usart_sendhexl(cmdcode);
                                usart_transmit('/');
                                usart_sendhexb(cmdlen);
                                // usart_send_nl();
                                // break;
                            }
                            default: {
                                cmdcode = 0;
                                cmdlen = 0;
                                break;
                            }
                        }
                    #endif

                        if (decoded == '?') {
                            if (polarity) {
                                usart_sendstr_P(PSTR("H "));
                            } else {
                                usart_sendstr_P(PSTR("L "));
                            }
                            usart_sendhexl(width);
                            usart_transmit('|');
                        }
                        if (decoded == ' ' || decoded == '?') {
                            usart_send_nl();
                        }

                    #if 0
                    #endif
                    }
                }
                break;
            }

#if 1
            case 'I': {
                sdcard_slow_mode();
                usart_sendstr_P(PSTR(" / disk init...\n"));
                unsigned char res = disk_initialize(0);
                usart_sendstr_P(PSTR("result of disk init = 0x"));
                usart_sendhexb(res);
                usart_send_nl();
                if (res == 0) {
                    /* fast mode is needed to sustain the demands of sound-play */
                    sdcard_fast_mode();
                    usart_sendstr_P(PSTR("SPI fast mode set.\n"));
                } else {
                    usart_sendstr_P(PSTR("WARNING: SPI fast mode NOT set.\n"));
                }
                break;
            }

            case 'S': {
                usart_sendstr_P(PSTR(" / disk status...\n"));
                unsigned char res = disk_status (0);
                usart_sendstr_P(PSTR("result of disk status = 0x"));
                usart_sendhexb(res);
                usart_send_nl();
                break;
            }

#if 0
            case 'G': {     // disk get sector
                char lba_str[30];
                int i;
                for (i = 0; i < SBUF_SIZE; i++) sbuf[i] = 0;
                
                usart_sendstr_P(PSTR(" / disk read: Enter LBA in hex = "));
                usart_getline(lba_str, 30);
                DWORD sector = hstr_to_ulong(lba_str);
                usart_sendstr_P(PSTR("\nLBA=0x"));
                usart_sendhexl(sector);
                
                DRESULT res = disk_read(0, (BYTE*)sbuf, sector, 1);
                usart_sendstr_P(PSTR("\nresult of disk read = 0x"));
                usart_sendhexl(res);
                usart_send_nl();
                
                if (res == RES_OK) {        // ok
                    for (i = 0; i < SBUF_SIZE; i++) {
                        usart_sendhexb(sbuf[i]);
                        if ((i & 0x0F) == 0x0F) {
                            usart_send_nl();
                        }
                    }
                }
                usart_send_nl();
                
                break;
            }
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

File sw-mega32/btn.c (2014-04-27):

#include "loop.h"
#include "clock.h"
#include <avr/io.h>

#define PIN_BTN1        (PIND & 0x10)
#define PIN_BTN2        (PIND & 0x20)
#define PIN_BTN3        (PIND & 0x40)
#define PIN_BTN4        (PIND & 0x80)
#define BTNBITS_MASK    0xF0


static uint8_t g_btn_cnt[4];
static uint8_t g_btn_states = 0;


void btn_init()
{
    /* buttons are inputs */
    DDRD &= ~BTNBITS_MASK;
    /* enable Pull-Up for button pins */
    PORTD |= BTNBITS_MASK;
}


static void btn_check(uint8_t pin, uint8_t idx)
{
    const uint8_t mask = 1 << idx;

    if (pin) {
        /* decrement */
        if (g_btn_cnt[idx] > 0) --g_btn_cnt[idx];
    } else {
        /* increment */
        if (g_btn_cnt[idx] < 15) ++g_btn_cnt[idx];
    }

    if ((g_btn_cnt[idx] == 0) && (g_btn_states & mask)) {
        g_btn_states &= ~mask;
        message_t *nmsg = loop_put_msg_begin();
        nmsg->cmd = Cmd_ButtonRelease;
        nmsg->arg1i = idx;
        loop_put_msg_end(nmsg);
    }

    if ((g_btn_cnt[idx] == 15) && !(g_btn_states & mask)) {
        g_btn_states |= mask;
        message_t *nmsg = loop_put_msg_begin();
        nmsg->cmd = Cmd_ButtonPress;
        nmsg->arg1i = idx;
        loop_put_msg_end(nmsg);
    }
}


int8_t btn_process(const message_t *msg)
{
    int8_t msg_recognized = 1;

    switch (msg->cmd) {
        case Cmd_ClockTick:
            btn_check(PIN_BTN1, 0);
            btn_check(PIN_BTN2, 1);
            btn_check(PIN_BTN3, 2);
            btn_check(PIN_BTN4, 3);
            break;

        default:
            msg_recognized = 0;
            break;
    }


    return msg_recognized;
}
